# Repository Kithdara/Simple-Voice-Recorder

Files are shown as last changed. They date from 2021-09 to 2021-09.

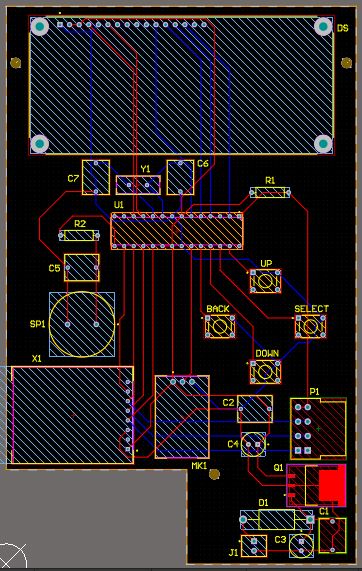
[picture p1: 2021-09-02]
Final PCB Design/Images/PCB layout - 2D view.JPG

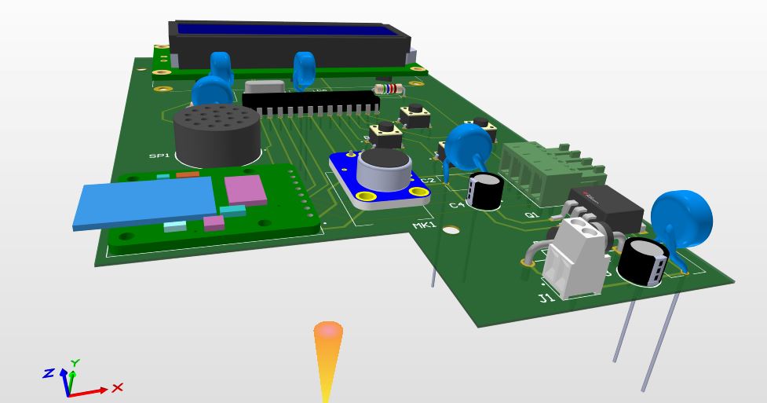
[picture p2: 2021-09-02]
Final PCB Design/Images/PCB layout - 3D view - 2.JPG

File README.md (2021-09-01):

# Simple-Voice-Recorder

We created a "Simple Voice Recorder" for our **Semester 2** Lab project at the Department of Electronic and Telecommunication Engineering, University of Moratuwa. 

**TASK** : Design and implement a simple voice recorder capable of recording, saving, selectively playing back multiple voice recordings, and adding adjustments to the spectrum during playback. 

Our project was successful in recording, saving, and playing back up to three recordings. Furthermore, we were successful in adding three adjustments; Down sampling, enhancing, shifting to the spectrum during playback. 

Recording and playback of our voice recorder are based on the **TMRpcm library** which samples at **16 kHz** and encodes **8 bits per sample**. Voice recordings were saved on an SD card. The final breadboard design, based on the **ATmega328-PU** single-chip microcontroller consists of four push buttons that interact with the user interface through an LCD. Our project is complete with a validated PCB and Enclosure design.

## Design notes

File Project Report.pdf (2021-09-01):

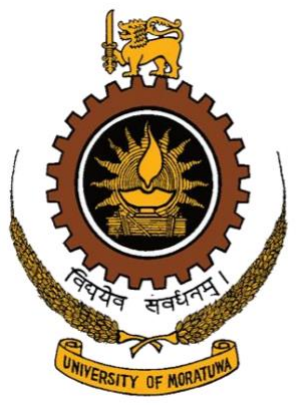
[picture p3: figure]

Priyashan, B.W.S. | 190476V
Punsara, K.K.S. | 190481G
Rajapaksha, R.M.P.A.P. | 190484T
Ranasinghe, K.K.H. | 190494A

Supervisor: Mr. Sahan Liyanaarachchi

August 2021

## Simple Voice Recorder

Department of Electronic and Telecommunication Engineering
University of Moratuwa

This report is submitted as partial fulfilment of module EN1093

## Abstract

We were given the task to design and implement a simple voice recorder capable of recording,

saving, selectively playing back multiple voice recordings, and adding adjustments to the spectrum

during playback. Our project was successful in recording, saving, and playing back up to three

recordings. Furthermore, we were successful in adding three adjustments; down sampling, enhancing,

and shifting to the spectrum during playback. Recording and playback of our voice recorder are based

on the TMRpcm library which samples at 16 kHz and encodes 8 bits per sample. Voice recordings are

saved on an SD card. The final breadboard design, based on the ATmega328-PU single-chip

microcontroller consists of four push buttons that interact with the user interface through an LCD. Our

project is complete with a validated PCB and Enclosure design.

## Table of Contents

1. Introduction.

The main goal of this project was to design and implement a simple voice recorder that

is capable to sample, encode and store the bit stream of the given sound source.

The Voice recorder that was developed by us is powered by an Atmega32

microcontroller, and it is capable of doing three main tasks. There are,

### 1. Record and save multiple voice recordings

- The Voice recorder is able to record up to 3 recordings (16 kHz

sampling rate and 8-bit PCM resolution) and save them on an SD card.

### 2. Selectively playback the recordings

- Users can select recordings that are saved in SD card through the

menu and playback them

### 3. Do minor adjustments to its spectrum during playback

- Users can add three adjustments to recordings. There are,
- Frequency shift
- Frequency scaling
- Selective enhancement of the spectrum.

In the designing stage of this project, we used many software tools such as Microchip

studio for coding, Matlab for calculations, Proteus for simulations, Altium for PCB design, and

Solidworks for enclosure design.

The following is the complete report of the challenges that we faced during the project

and how we solved them.

## 2. Methodology

### 2.1 Audio Recording / Analog to Digital Conversion

When we capture a sound wave using a microphone, it creates an analog voltage signal

proportional to the pressure variation of that sound. But, for storing, transferring, and

modifying purposes, it would be more convenient if this analog information can be converted

into a set of digital data.

The ATmega328P microcontroller includes an inbuilt ADC module that makes it

appliable in designing a voice recorder. This module has a resolution of up to 10 bits per sample

and has a conversion time from 65 to 260 µs. This module is connected to 8 multiplexed single-

ended input channels coming from the pins AD0 to AD7 of port A.

### 2.1.1 Pulse Code Modulation (PCM)

Pulse Code Modulation (PCM) is a commonly used technique to convert analog

information into digitized data. There are 3 main steps in this conversion technique.

### 1. Sampling

In this step, the analog signal is sampled at constant intervals in time known as the

Sampling Intervals. The corresponding Sampling Frequency is determined by the Nyquist

Sampling Theorem, which states that a bandlimited continuous-time signal can be sampled and

perfectly reconstructed from its samples if the waveform is sampled over twice as fast as its

highest frequency component. According to the above theorem, when implementing a Voice

Recorder, the frequency of the sampling process must be at least 8 kHz, since the highest

frequency of a voice signal is considered to be 4 kHz.

### 2. Quantizing

After the sampling process, the signal is quantized, i.e. each sample is approximated to

one of several selected discrete levels. Depending on the way of choosing these quantization

levels, this step can be achieved in two different techniques, known as Uniform and Non-

Uniform Quantization. In the Uniform Quantization, all the quantizing levels are equally

spaced in amplitude, in contrast to the Non-Uniform Quantization where the quantizing levels

are specifically chosen to capture more common lower amplitude signals in a higher resolution.

However, since the ADC module in the ATmega328P provides 1024 (= 2

10) uniform

quantizing levels, in this project, we have used a quantization method consisting of 256 (= 2

8
)

equally spaced quantizing levels. This much of a resolution is practically enough to capture

common electrical signal variations in an amplified audio signal.

### 3. Encoding

In the Encoding process, each sample is represented by a digital code unique to the

corresponding quantization level of the sample. Since a number of 2

8
levels have been used

for quantization in this case, each sample would be replaced by an 8-bit binary code; a byte.

### 2.1.2 TMRpcm Library

In this Voice Recorder Design, both the audio recording and audio playback

implementations are based on the TMRpcm library. TMRpcm is an Arduino library that

enables Asynchronous Playback of 8-bit, 8-32 kHz sampling rate, mono type WAV audio files

stored in an SD card. (The asynchronous playback specifies that the playing of an audio file

does not block the execution of the other codes in the main loop.) This library can be used on

many of the Arduino development boards such as Uno, Nano, Mega, and even on the

corresponding Atmel microcontrollers including ATmega328P.

This library provides a broad range of functions regarding audio recording and playback

and some of those main functions are listed down below.

- TMRpcm.play(filename); plays a WAV file
- TMRpcm.stopPlayback(); stops the music, but leaves the timer running
- TMRpcm.isPlaying(); returns 1 if music is playing, 0 if not
- TMRpcm.pause(); pauses/unpauses playback
- TMRpcm.volume(0); 1 (up) or 0 (down) to control volume
- TMRpcm.setVolume(0); set volume level from 0 to 7
- TMRpcm.startRecording(filename, sample rate, pin); start recording audio
- TMRpcm.stopRecording(filename); stop recording audio

Even in the TMRpcm library, the same Pulse Code Modulation (PCM) technique is

used to digitally represent the audio data. In order to understand how this PCM method is

implemented in TMRpcm, we have to take a look at how it uses the inbuilt ADC module and

the corresponding registers.

### 2.1.3 The Implementation of Analog to Digital Conversion in TMRpcm Library

Since the PRADC (Power Reduction ADC bit) of the PRR (Power Reduction Register)

has an initial value of logical 0 (i.e. power reduction is disabled), by default, the ADC module

is automatically powered up when the clock signal is supplied to the microcontroller. (refer to

Figure 1)

Figure 1 - PRR

Prior to performing any conversion, the ADC module must be enabled by setting the

ADEN (ADC Enable bit) of ADCSRA (ADC Control and Status Register - A) to a logical one.

This step is implemented in the TMRpcm library by the following line of code.

ADCSRA |= _BV(ADEN) | _BV(ADATE); //ADC Enable, Auto-trigger enable

Figure 2 - ADCSRA

Then the sampling frequency must be set for the digital conversion. The input clock

frequency for the ADC module is determined by dividing the system clock frequency (16 MHz)

by the prescaling factor given by the bit combination of the ADC Prescaler Select bits

(ADPS2:0) in the ADCSRA register. (refer to Figure 2) And when calculating the sampling

frequency, note that a normal conversion takes 13 ADC clock cycles. (refer to Table 1)

Table 1 - the sampling frequency calculation

ADPS2 | ADPS1 | ADPS0 | Prescaling Factor | ADC Clock Frequency (16 MHz / prescaling factor) | Sampling Frequency (ADC Clock frequency / 13 clock cycles)
0 | 0 | 0 | 2 | 8 MHz *
0 | 0 | 1 | 2 | 8 MHz *
0 | 1 | 0 | 4 | 4 MHz *
0 | 1 | 1 | 8 | 2 MHz *

1 | 0 | 0 | 16 | 1 MHz | 76.923 kHz
1 | 0 | 1 | 32 | 500 kHz | 38.461 kHz
1 | 1 | 0 | 64 | 250 kHz | 19.230 kHz
1 | 1 | 1 | 128 | 125 kHz #

* not achievable due to the performance limitation of the ADC module.

not achievable in the TMRpcm library

When initializing a recording using the TMRpcm library, the sampling frequency must

be given as an input to the startRecording function. Then the library will automatically set the

prescaler bits to obtain the required sampling frequency. The corresponding coding from the

library is shown below.

byte prescaleByte = 0;

if (SAMPLE_RATE < 18000) {prescaleByte = B00000110;} //ADC division factor 64 (16MHz / 64 / 13clock cycles = 19230 Hz Max Sample Rate)
else if (SAMPLE_RATE < 27000) {prescaleByte = B00000101;} //32 (38461Hz Max)
else {prescaleByte = B00000100;} //16 (76923Hz Max)

ADCSRA = prescaleByte; //Adjust sampling rate of ADC depending on sample rate
Due to the performance limitation, the maximum possible sampling frequency is

limited to 76 kHz.

By setting up the REFS1 and REFS0 (Reference Selection bits) in the ADMUX (ADC

Multiplexer Selection Register), the voltage reference for the ADC can be selected. (refer to

Figure 3 and Table 2)

Figure 3 - ADMUX

Table 2 - Reference Selection bit configuration

REFS1 | REFS0 | Voltage Reference Selection
0 | 0 | AREF, internal VREF turned off
0 | 1 | AVCC with external capacitor at AREF pin
1 | 0 | Reserved
1 | 1 | Internal 1.1V voltage reference with external capacitor at AREF pin

The TMRpcm library is set for the second voltage reference shown above, where the

voltage reference is taken through the AVCC pin by connecting it directly to the VCC and

bypassing it to the ground through a capacitor; the same configuration in an Arduino Uno

board. Rifer the following code from the TMRpcm library and Figure 3.

ADMUX |= _BV(REFS0) | _BV(ADLAR); //Analog 5v reference, left-shift result so

only high byte needs to be read

Figure 4 - Voltage Reference in an Arduino Uno

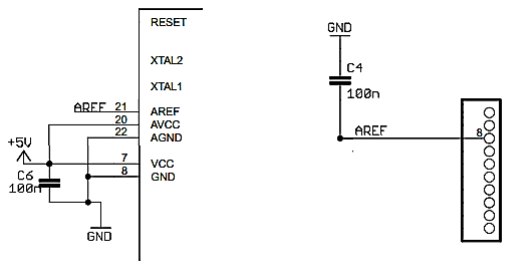
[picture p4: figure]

Then the analog input channel can be selected by changing the bits in the Analog

Channel Selection bits; MUX3:0 in the ADMUX register. Refer to Figure 3 and Table 3.

Table 3 - Analog Channel Selection bit configuration

MUX3 | MUX2 | MUX1 | MUX0 | Single-Ended Input
0 | 0 | 0 | 0 | ADC0
0 | 0 | 0 | 1 | ADC1
0 | 0 | 1 | 0 | ADC2
0 | 0 | 1 | 1 | ADC3
0 | 1 | 0 | 0 | ADC4
0 | 1 | 0 | 1 | ADC5
0 | 1 | 1 | 0 | ADC6
0 | 1 | 1 | 1 | ADC7

Same as with the sampling frequency, the pin that is used to give the analog input must

be given as an input to the startRecording function by using the corresponding Arduino analog

pin notation (from A0 to A7). This parameter (“pin”) will be then taken as a byte and the

corresponding input pin will be connected to the ADC.

#if defined(ADMUX)

ADMUX = (pin & 0x07); // same as (pin & 0b00000111)
#endif

After setting the above bit configurations, the sampling process can be begun. To start

an analog to digital conversion manually, the ADSC (ADC Start Conversion bit) in the

ADCSRA register must be written to a logical one. (refer to Figure 2) During the conversion

period, this bit will remain as a one, and when the conversion is completed, the value will return

to zero. Thus, to implement a recurring sampling process using this method, the ADSC bit has

to be written up again and again manually.

As a more convenient alternative, the Auto Triggered Mode can be used to achieve a

repeating sample-taking process. In this method, the conversion will be continuously repeated

periodically based on a trigger source selected, i.e. a conversion will be automatically started

on each positive edge of the trigger signal. To enable this auto triggered mode, a logical one

must be written to the ADC Auto Trigger Enable bit (ADATE) in ADCSRA (refer to Figure

2), and for selecting the preferred trigger source, the bit selection of the ADC Auto Trigger

Source bits (ADTS2:0) in the ADC Control and Status Register - B (ADCSRB) must be set.

Figure 5 - ADCSRB

In the TMRpcm library, a previously set timer that is created using the given sampling

rate is used as the auto trigger source. Refer to the following lines of code to see the selected

bit configuration in the ADTS bits used in the library.

ADCSRA | |= | _BV(ADEN) | | | _BV(ADATE); //ADC Enable, | Auto-trigger enable
ADCSRB | |= | _BV(ADTS0) | | | _BV(ADTS2); //Attach ADC start to TIMER1 Compare Match B

flag

After the conversion is completed, the encoded value is stored in the ADC Data

Registers which consist of two 8-bit registers; ADCL and ADCH. When the result is left-

adjusted by writing the ADLAR (ADC Left Adjust Result bit) in the ADMUX register (refer to

Figure 3), the 8 most significant bits of the 10-bit value will be written to the ADCH register

left-adjusted, and the remaining 2 bits will be written on the ADCL. (refer to Figure 6)

Figure 6 -
ADLAR and
ADCH

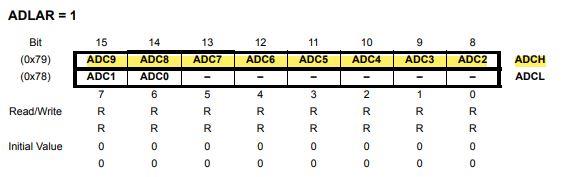
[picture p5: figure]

When only an 8-bit precision is required (as the case in the TMRpcm library), only

reading the ADCH register is enough. And then, this read encoded sample value will be

transferred into the SD card module connected to the microcontroller to be stored in the

corresponding audio recording WAV file.

This is the menu that we will see when our

voice recorder is power on.

If we select record action in the main menu,

we will go to recording menu and if we select

stop recording, we will go back to main

menu and our recording will be saved in SD

card.

If we go to recordings after record, we will

see the newly recorded file in the play list.

Also, we can go up and down and select

previously recorded recordings too.

Figure 8 - Main Menu | Figure 7 - Recording Menu

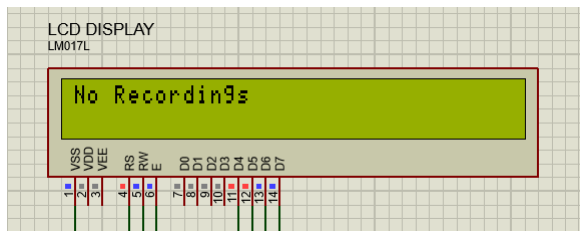
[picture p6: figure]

Figure 9 - Play List

If we go to the recordings without recording

any voice, we will be indicated that there are

no recordings.

### 2.2 User Interface

We have four push buttons to control the display. Those four buttons are up button,

down button, select button and back button.

In our user interface we have 4 main parts. Those are,

- Main menu
- Recording menu
- Play list
- Playing menu

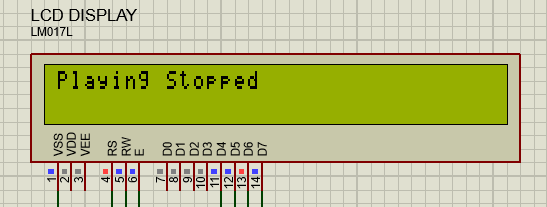
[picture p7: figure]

Figure 10 - Playing Menu

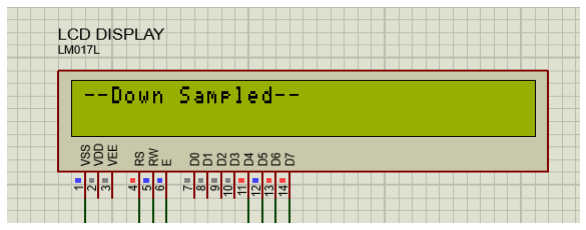
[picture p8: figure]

Figure 11

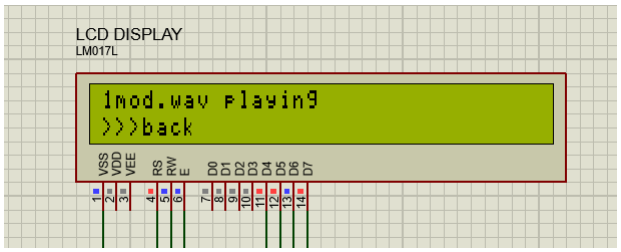
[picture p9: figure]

Figure 12

If we select a recording to play we can play it and if we select the given

back option voice recorder will stop playing the recording.

After creating the new audio file with the effect, we can play the

recording with added effect.

If we play the modified recording first voice recorder will process the audio

file and create a new modified audio file with selected effect.

### 2.3 Prototype Design

The main requirement of the project was to successfully record and save multiple

recordings. And then, selectively playback the recordings.

### 2.3.1 Breadboard design using Arduino microcontroller

Initial design of the project was done on a breadboard using the Arduino micro-

controller to implement and validate our ideas. We were successful in recording and saving up

to 3 recordings. Due to the instability of the code when program memory usage is maximum,

we had to limit the maximum number of recordings to 3.

Push buttons were successfully integrated with the LCD display for a smooth

interaction with the user interface. Voice recorded using the microphone module was sampled

at 16 kHz and encoded at 8 bits per sample using the TMRpcm library in Arduino. Recordings

were saved in .wav format. We were successful in selectively playing the 3 recordings using

the speaker. Initial design on the breadboard using the Arduino micro-controller proved

successful. Next, we shifted our prototype on the breadboard using an ATMEGA 328-PU

single-chip microcontroller.

### 2.3.2 Breadboard design using ATMEGA 328-PU

When shifting our initial design to the ATMEGA 328-PU chip microcontroller, several

codes were converted to AVR. As we implemented our main idea around the TMRpcm library,

most of the code was converted to AVR from the Arduino sketch. Since the sound source was

sampled at 16 kHz, a clock speed of 16 MHz is required. To fulfil this requirement an external

16 MHz crystal oscillator was used with the chip.

When using a 16 MHz crystal oscillator with ATMEGA 328-PU we had to first change

the “Fuse Low Bytes”. There are a total of 19 fuse bytes used in the ATMEGA 328-PU, they

can be categorized under “Extended Fuse Bye”, “Fuse High Byte” and “Fuse Low Byte”.

Setting up an external crystal oscillator does not require changing of Extended and Fuse High

Bytes.

When selecting the clock source for the ATMEGA we had to consider the following

process according to Table 4 given below. First of all, it should be noted that, a fuse byte is

unprogrammed if it is set to 1.

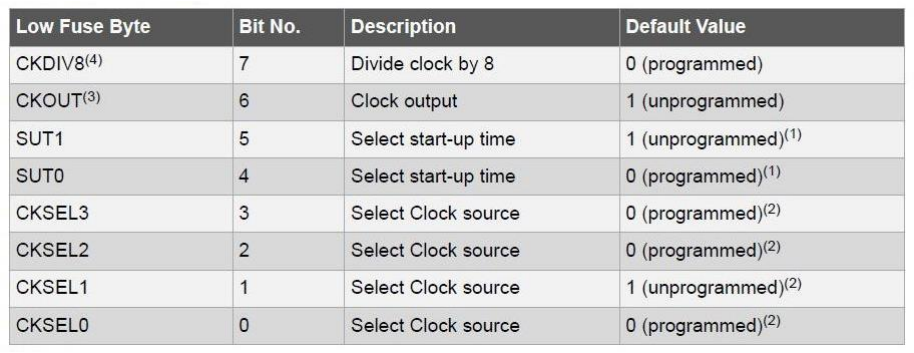
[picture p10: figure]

CKDIV8, controls whether the clock rate should be divided by 8 or not. Since, we use

an external 16 MHz crystal oscillator, bit 7 was unprogrammed (1).

CKOUT, sets whether clock output is present in PORTB0 of the microcontroller. There

was no need for this setting in our project, therefore bit 6 was unprogrammed (1).

SUT1 and SUT0 sets the startup time of the micro controller, which prevents the chip

from attempting to start before the supply voltage has had time to reach an acceptable minimum

level. Default setting of 10 is for a startup delay of six clock cycles from power-down and

power-save and an addition startup delay of 14 clock cycles plus 65ms for RESET. According

to Table 5, on the safe side for a low power crystal oscillator, a maximum delay of 16,000

clock cycles from power-down and power-save is needed. Therefore, both SUT1 and SUT0,

i.e. bits 5 and 4 is unprogrammed (1). In addition, CKSEL0, i.e. bit 0 is also unprogrammed

(1).

Table 4 - Fuse Low Byte

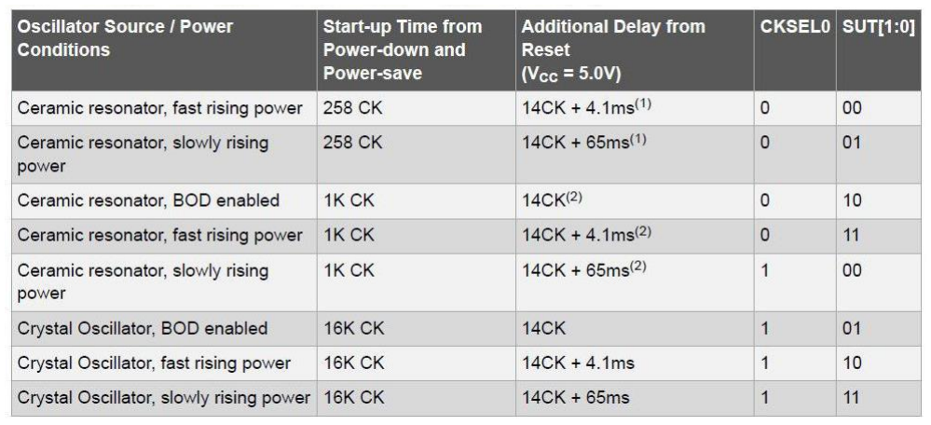
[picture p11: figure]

Bits 3 through 0 are used to select the clock source. According to Table 6, we need a

low power crystal oscillator, which means bits 3 to 0 can takes values in the range 1111 - 1000.

According to Table 7, it is stated that for a frequency range of 8 - 16 MHz CKSEL[3:1] must

be set to 111. Range of capacitors that should be connected to the oscillator is recommended

to be between 12 and 22pF. We have used two 22 pF capacitors in our design.

Table 5 - Start up times for the Low Power crystal oscillator clock selection

Table 6 - Device Clocking Options Select

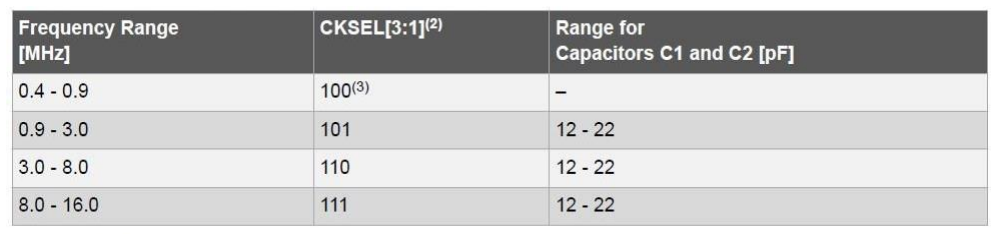
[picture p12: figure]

In conclusion,

Table 8 - Fuse Low Byte for 16 MHz crystal oscillator

CKDIV8 | CKOUT | SUT1 | SUT0 | CKSEL3 | CKSEL2 | CKSEL1 | CKSEL0
1 | 1 | 1 | 1 | 1 | 1 | 1 | 1

Therefore, the new Fuse Low Byte should be 11111111, which is 0xFF in hexadecimal

notation.

After figuring out the correct Fuse Low Byte, fuse bytes were burnt to the

microcontroller using avrdude and Arduino as ISP. AVRDUDE is command line driven utility

required to program changes to the ATMEGA 328-PU or any other Atmel microcontroller.

First, the Arduino microcontroller was connected to the laptop and “Arduino as ISP”

sketch was uploaded to the Arduino. At this stage, there should be no connections between

external components and the Arduino.

Then connections must be made between the Arduino and the microcontroller as

follows;

Arduino Pin 13 - PB5 / SCK

Arduino Pin 12 - PB4 / MISO

Arduino Pin 11 - PB3 / MOSI

Arduino Pin 10 - PC6 / RESET

After the following connections were set up, fuse low bytes were burnt to the

microcontroller. This procedure is repeated to burn hex codes to the micro controller.

We were also successful in recording, saving and playing back up to 3 recordings using

the ATMEGA 328-PU microcontroller. For the ease of shifting from Arduino prototype to the

microcontroller prototype on the breadboard, the initial connections were kept the same.

Table 7 - Low power crystal oscillator operating modes

Unfortunately, due to a fault in the microphone module, there was a significant noise

in all the recordings. Because of the noise, the clarity of the recording was quite low. But, due

to the noise the recording when played through the speaker lacked clarity. But, when the

recordings were listened from the laptop, the voice recordings could be heard even with the

noise.

PWM output from the micro-controller cannot be directly played through a speaker as

PWM is a digital signal. Therefore, a RC filter design was used as a low-pass filter and driver

for the speaker.

When calculating values for the resistor and capacitor, we wanted the cut-off frequency

to be 4kHz to allow only voice to be output to the speaker. A 0.22μF capacitor required a

resistor of 150Ω to apply the low pass filter at the required frequency. But, since a RC filter is

a passive filter design, the total output voltage had a significant decrease. This led to a low

volume output from the speaker.

Another requirement of the project was to apply adjustments to the spectrum during

playback. Although, this was not implemented in the main code due to instability, we were

successful in applying 3 effects to a recorded .wav file using the micro-controller on the

breadboard. The 3 effects namely; Down sampling, Enhance and Shifting could be

demonstrated individually in the prototype. The above effects were added to a saved recording

in the SD card, and played using the laptop. Further information on effects applied is discussed.

### 2.4 Components

### 2.4.1. Microphone module

The microphone module used for the project was GY-MAX 4466. MAX 4466 with its

in-built adjustable gain and sound amplification was ideal for our requirement. Unfortunately,

the module used in the project had a significant noise added to the recordings.

### 2.4.2. Push buttons

Four 12mm tactile push buttons were used for UP, DOWN, SELECT and BACK

functions.

### 2.4.3. LCD Display

1602A (16x2) LCD display was used in the project. A potentiometer was used to

control the brightness of the display.

### 2.4.4. SD card module

Micro-SD Memory Card adapter was used to store and playback voice recordings. The

module consists of 6 pins which include Chip Select (CS), MISO, MOSI, SCK, VCC and GND.

A 7 GB SAMSUNG SD card was used with the module.

### 2.4.5. Speaker

8 Ohm 3W speaker was used to play the stored recordings.

### 2.4.6. Capacitors

One 0.22μF capacitors was used for the RC filter design. Two 22pF capacitors were

used to connect the 16 MHz crystal oscillator to ground.

### 2.4.7. Crystal oscillator

16 MHz crystal oscillator was used with the micro-controller.

### 2.4.8. Micro-controller

ATMEGA 328PU micro controller was used for the project. This micro-controller was

used as it was readily available and ease of burning hex files using Arduino as ISP.

### 2.4.9. Resistors

One 10 kΩ resistor was used to connect RESET pin of the micro-controller to 5V. One

150Ω resistor was used in the RC filter design.

Figure 13 - (from left to right, in order) GY MAX 4466, 12 mm tactile push buttons, 1602A LCD display, Micro-SD Memory Card Adapter, 8 Ohm 3W Speaker

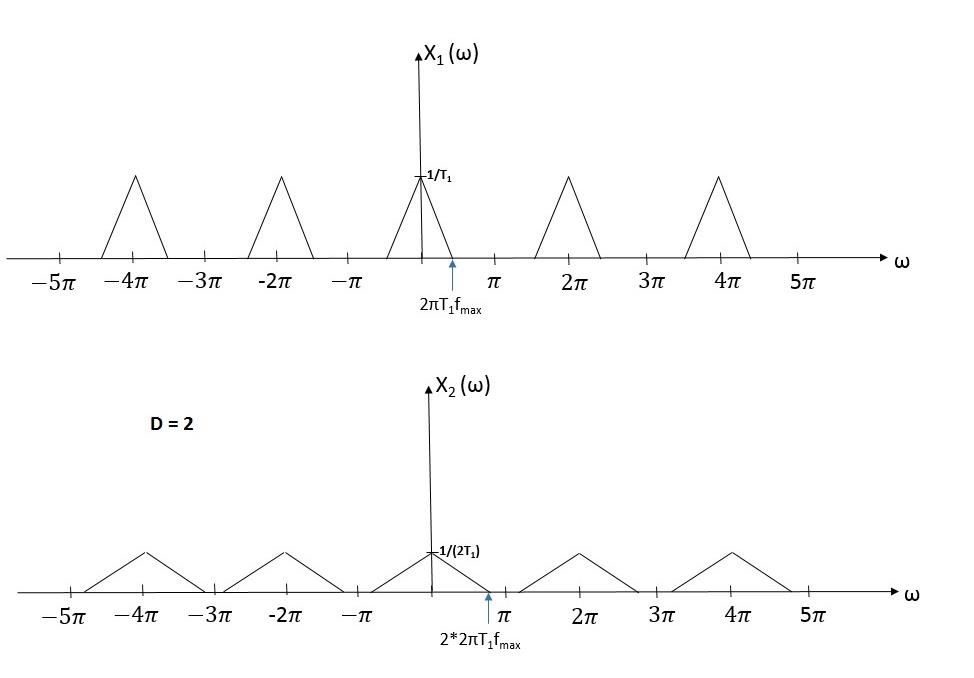
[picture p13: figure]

Figure 14 - spectrum before and after downsampling

### 2.5 Audio Enhancement Techniques

Our voice recorder has the ability to add three effects to the recorded voices. Those are

Frequency scaling, Selective Enhancing & Frequency shifting. To achieve these effects some

adjustments must be done to the spectrum of recorded voice samples. However, the processing

power of the Atmega32 microcontroller is not enough to add those changes directly to the

spectrum. So, we build algorithms to change time-domain sample values according to some

mathematical methods to achieve expected spectrum adjustments.

### 2.5.1 Frequency Scaling

The bandwidth of the recorded voice recorder is 4 kHz. The target of the frequency

scaling is, scale all frequency components in the range 0 – 8khz. To achieve this, we have to

downsample the voice file with the rate of 2. The spectrum of voice before and after

downsampling with the ratio of 2 is shown in the figure.

According to the figure, sampling frequency >= 4 × bandwidth to avoid distortion in

the spectrum.

Since the bandwidth of the voice recorder is 4 kHz, the Minimum sample rate of the

voice recorder is 16 kHz.

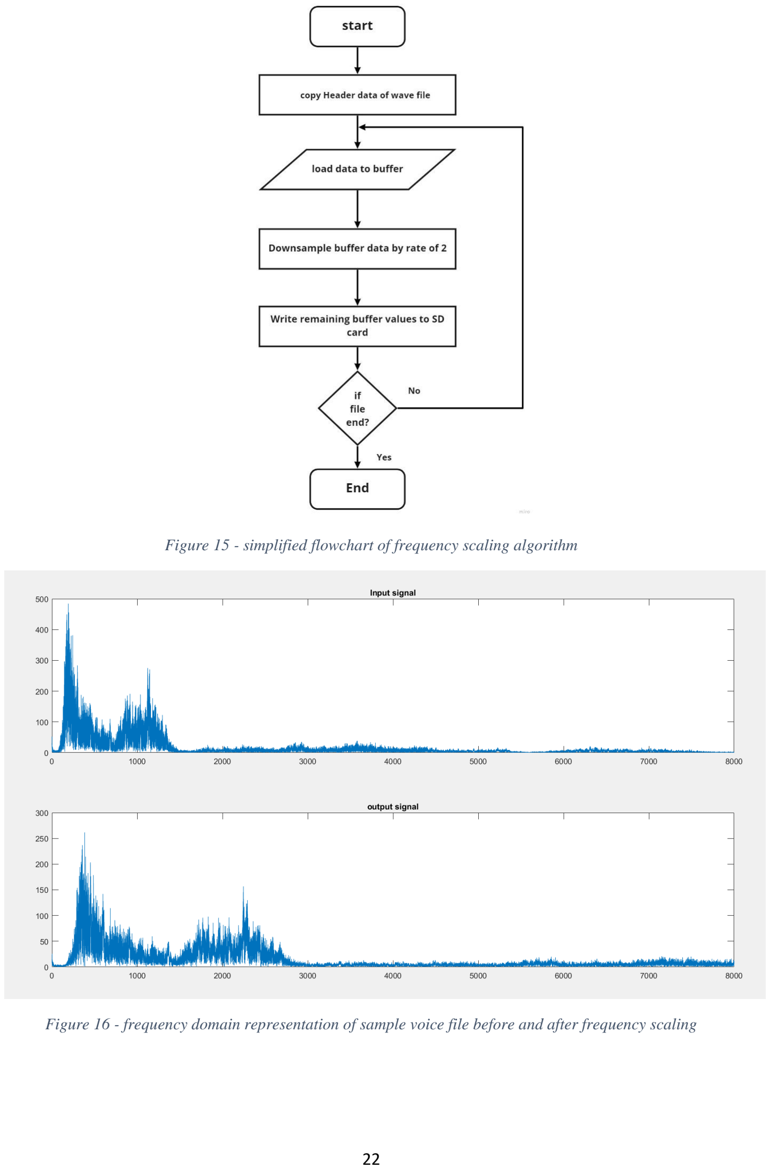
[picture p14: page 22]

Figure 15 - simplified flowchart of frequency scaling algorithm

Figure 16 - frequency domain representation of sample voice file before and after frequency scaling

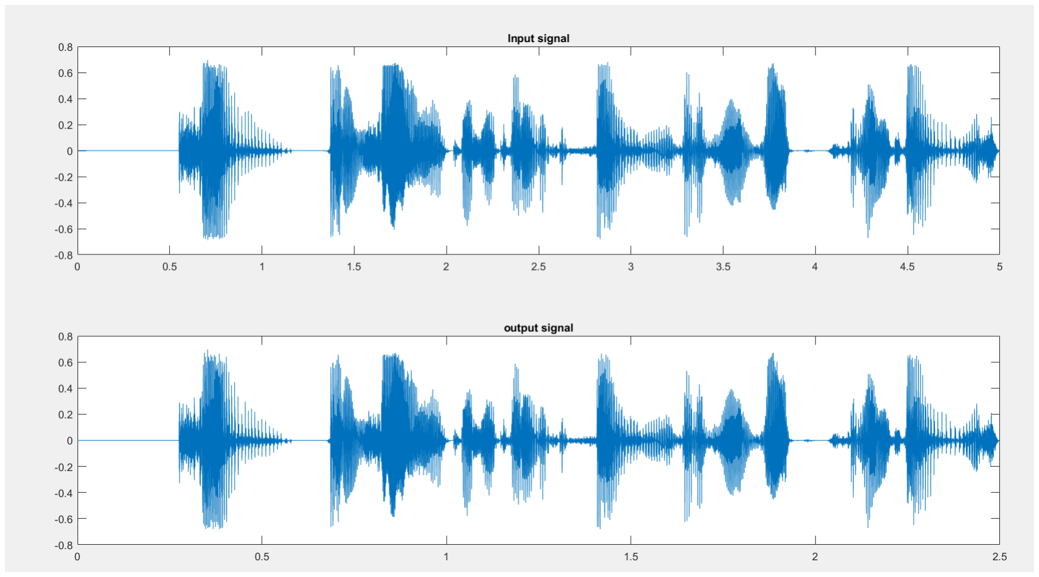
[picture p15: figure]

Figure 17 - time-domain representation of sample voice files before and after frequency scaling

### 2.5.2 Selective Enhancing

In selective enhancing, we divide the spectrum into two parts as low frequency range

(0 Hz < f < 2500 Hz) and High frequency range (2500 Hz < f < 4000 Hz). Then we enhance

the high-frequency range by increasing its amplitude by a factor of 8 and reduce the amplitude

of the low-frequency range by a factor of 1/8. However, since we are doing all calculations in

the time domain we have to use the convolution property for Fourier transform to enhance the

spectrum.

Equation 1 - convolution property

We can get filter coefficients of h(t) which have a gain of -9.03 dB for low-frequency

range and 9.03 dB gain for high-frequency range using Matlab.

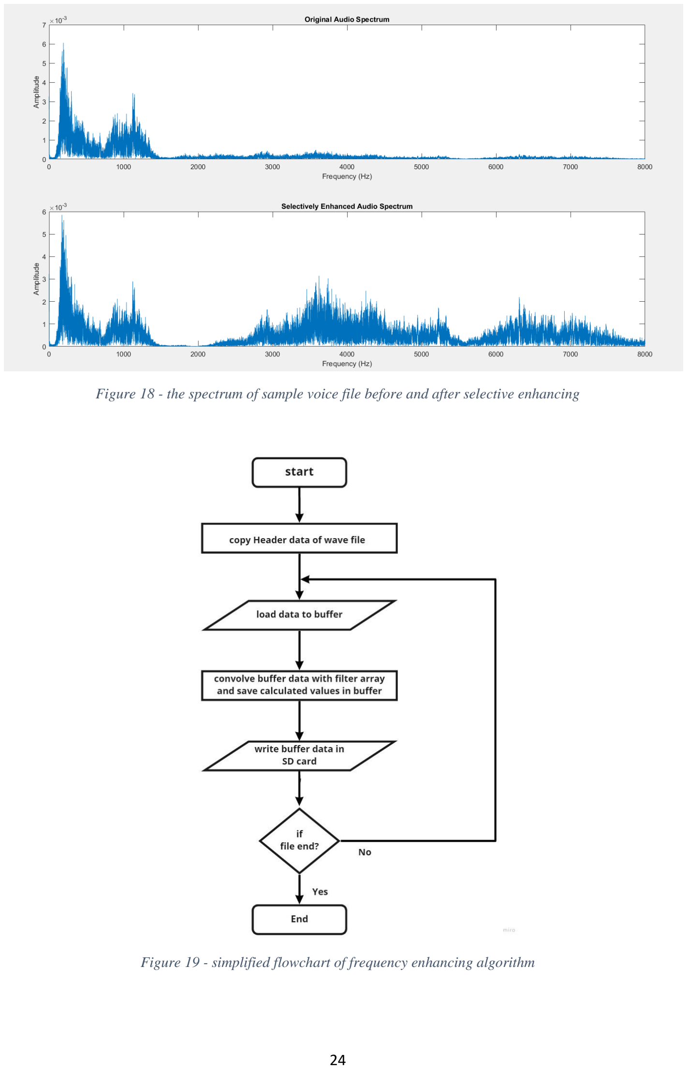
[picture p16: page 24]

Figure 18 - the spectrum of sample voice file before and after selective enhancing

Figure 19 - simplified flowchart of frequency enhancing algorithm

### 2.5.3 Frequency shifting

In the frequency shifting effect, we shift all frequency components in the spectrum to

higher frequencies by 2000 Hz. To do this process we used both convolution and multiplication

properties of Fourier transform.

Equation 2 - multiplication property

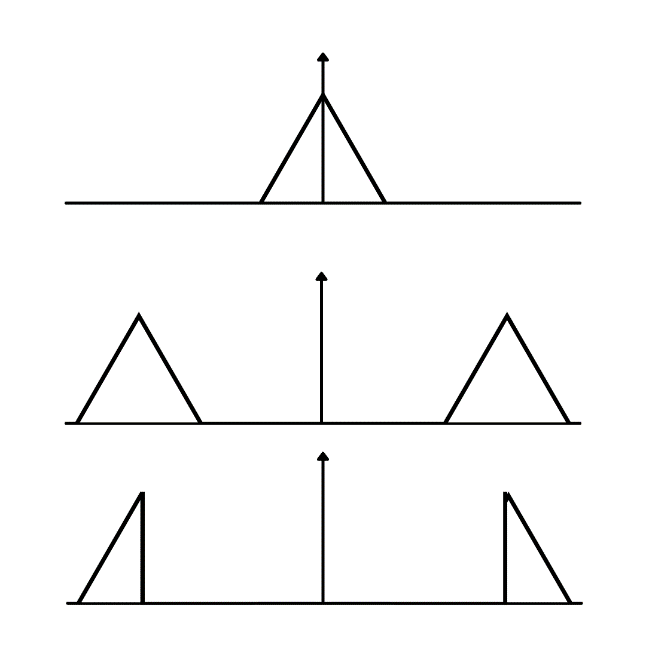
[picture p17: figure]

Figure 20 - spectrum

x(t) = voice record

y(t) = cos(2πft)

ℎ(t) = high pass filter (cutoff frequency - f)

x(t)

### x(t)y(t)

### [x(t)y(t)] *h(t)

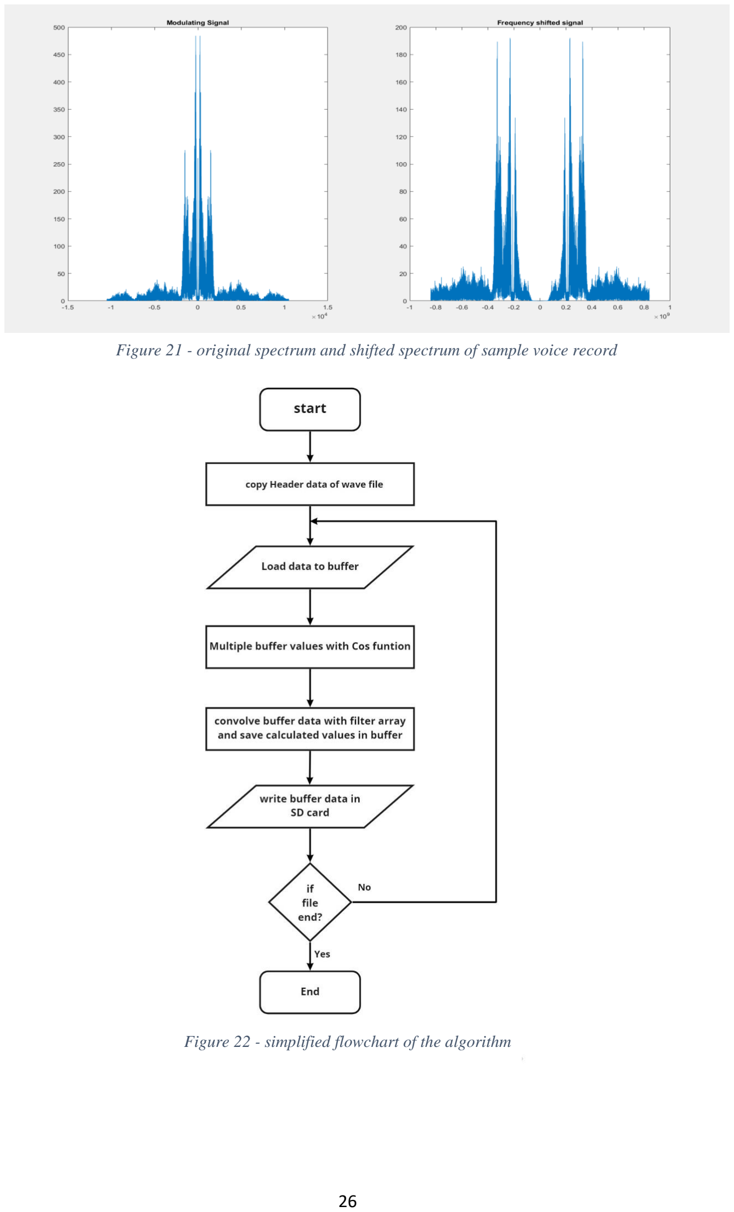
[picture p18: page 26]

Figure 22 - simplified flowchart of the algorithm

Figure 21 - original spectrum and shifted spectrum of sample voice record

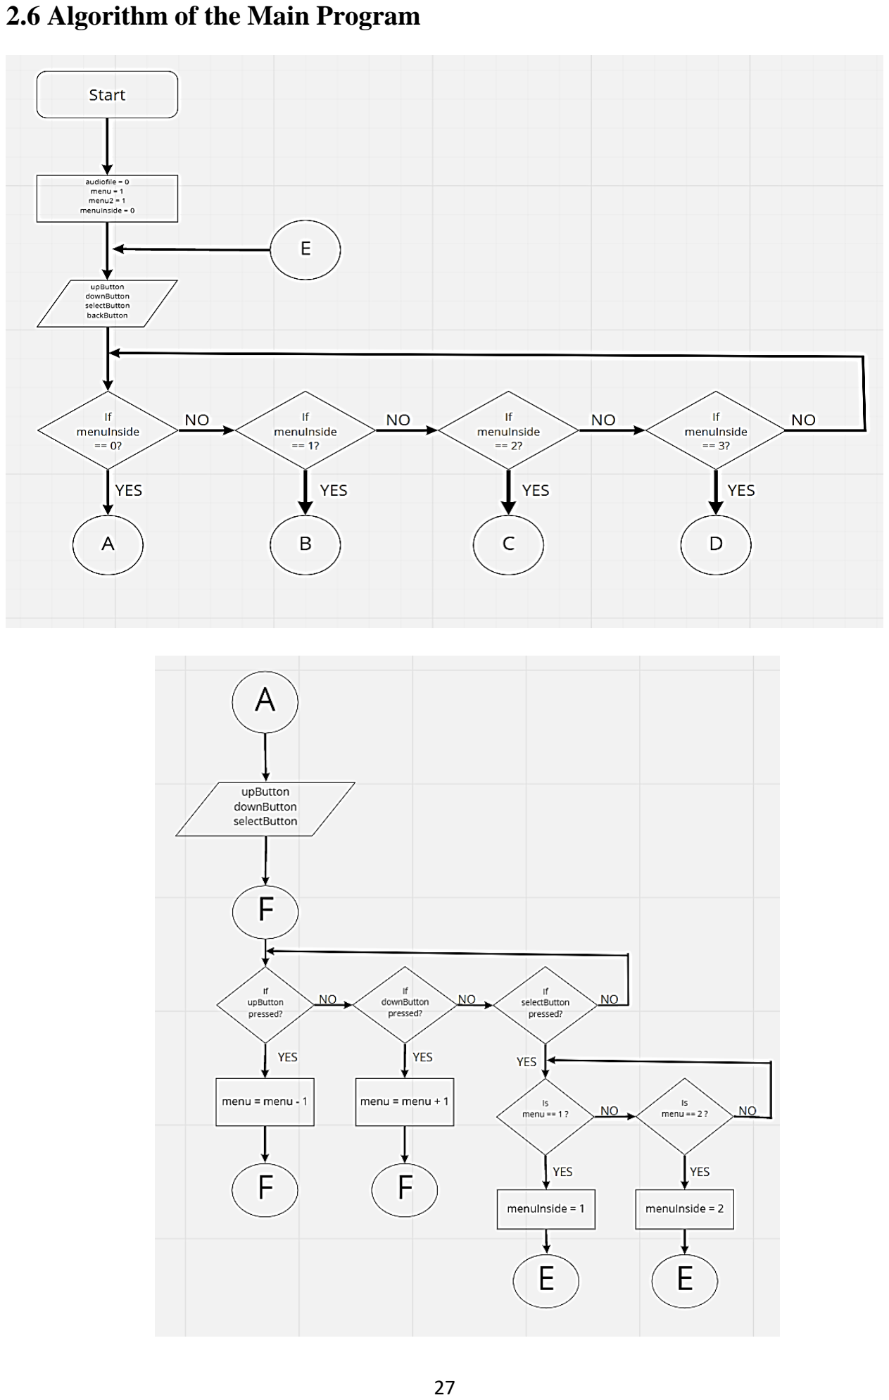
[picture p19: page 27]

### 2.6 Algorithm of the Main Program

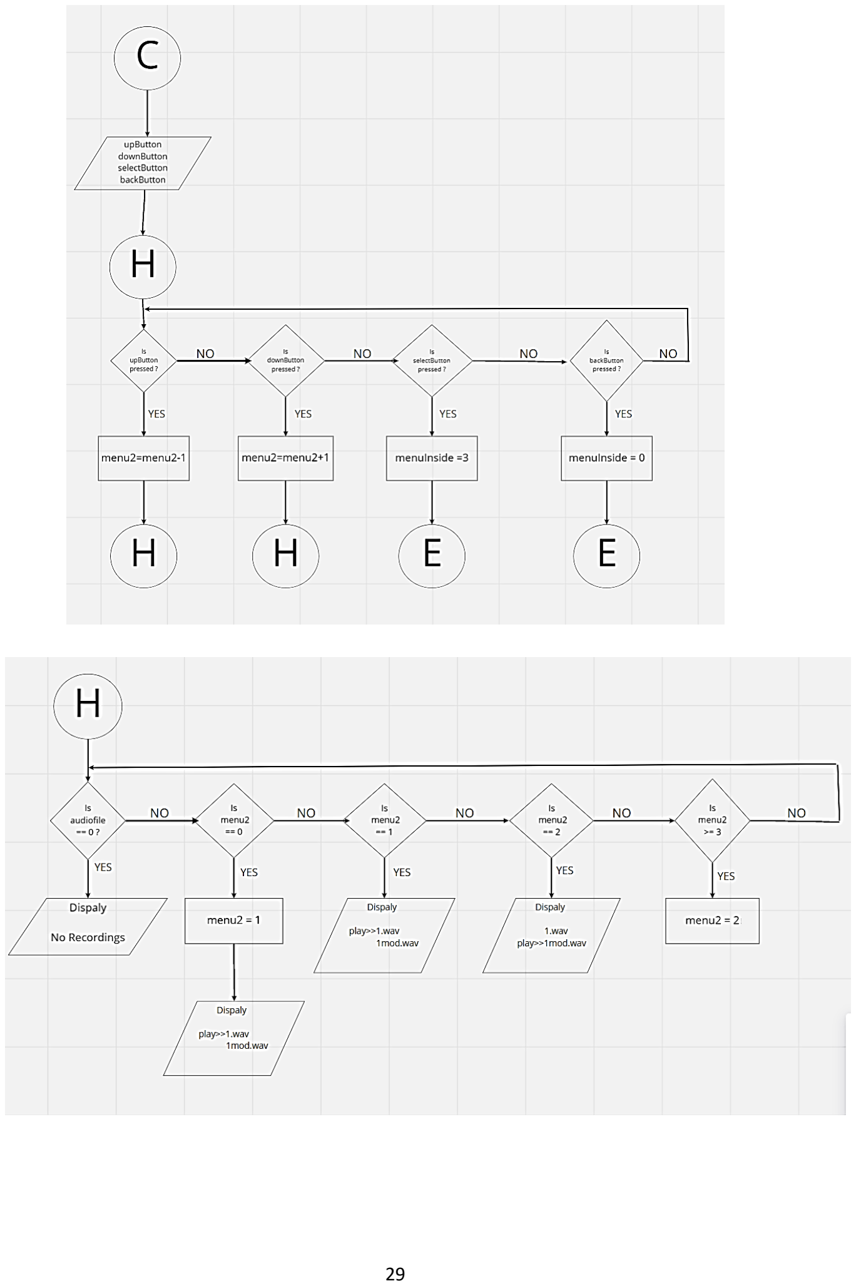
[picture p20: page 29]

## 3. Discussion

First of all, at the beginning of the project, we divided work with our four members.

Akila took the recording part and PCB designing part. Shivanka took the playback part and

breadboard implementation part. Kithdara took the Matlab coding part and adding the part of

the effects. Samal took the user interface part and enclosure designing part. The Hard-working

of our team members and correct guidance from our group instructors paves the way to a

successful project.

During this project, our team members faced some common problems. The main

problem was we had to work from home due to covid 19 pandemic situation. It was a new

experience and a challenge to us but doing regular zoom meetings with our instructors and

among us, we manage the pandemic situation. Apart from that lack of coding knowledge is

also a common problem we faced during this project. Regular group meetings and discussions

and doing research on the internet we managed to overcome that problem too.

When it comes to recording and play part, initially we tried to implement those in

Arduino simulation using RC ladder but later we used TMRpcm library. First, we tried to use

only play and record prat in library but it was unsuccessful, so we used whole library later.

Also, we managed to implement the required three effects (frequency scaling, selective

enhancing, frequency shifting) in Matlab. When we convert those 3 Matlab codes to Arduino

and AVR we faced some problems. Since the Arduino board has limited memory and ram, we

have to add additional loops and other necessary changes to implement those effects in

Arduino.

Also, we faced some problems when we combine codes to make our full code. Since

atmega328p microcontroller has limited memory and global variable memory we had to reduce

some features in the voice recorder. Finally, we were able to make a voice recorder that can

record 3 voice recordings and selectively playback the with frequency scaling effect.

When it comes to the breadboard implementation part we faced some problems too.

The main problem was due to the pandemic situation we cannot find the necessary parts needed

to project. We have to online order them and wait until they arrive. Also, we had a problem

with our microphone module and speaker module. We bought a microphone module with

adjustable gain but when we start recording from it there is a loud noise in the recorded audio file. We tried to manage that noise by adding a RC filter. We think an error in the microphone

module is the reason for this loud noise.

Also, we had a speaker module with an amplifier circuit but unfortunately, it burned.

So, we had to use an 8ohm speaker in our breadboard implementation without using

amplification. Also, in enclosure and PCB design, we faced some practical problems, but we

were able to solve them. Finally, with correct guidance and effort from our team members, our

group was able to make a working voice recorder.

## 4. References

Atmel Corporation. (n.d.). ATmega328P, 8-bit AVR Microcontroller with 32K Bytes In-System Programmable Flash, DATASHEET, ATmega328P (microchip.com) (https://ww1.microchip.com/downloads/en/DeviceDoc/Atmel-7810-Automotive-Microcontrollers-ATmega328P_Datasheet.pdf)

docr. (2019, February 27). Arduino ADC Programming. Retrieved from YouTube: https://youtu.be/YYE9jq5sXo4

Hienzsch, D. (n.d.). Arduino from scratch part 10 - ATmega328P subsystem. Retrieved from Rheingold Heavy: https://rheingoldheavy.com/arduino-from-scratch-part-10-atmega328p-subsystem/ (https://rheingoldheavy.com/arduino-from-scratch-part-10-atmega328p-subsystem/)

Smyth, T. (2019, October 15). Nyquist Sampling Theorem. Retrieved from http://musicweb.ucsd.edu/~trsmyth/digitalAudio171/Nyquist_Sampling_Theorem.html

TMRpcm/Home, https://github.com/TMRh20/TMRpcm/wiki, 2020

Learn About ATmega328P Fuse Bits and How to Use Them with an External Crystal Oscillator, Learn About ATmega328P Fuse Bits and How to Use Them with an External Crystal Oscillator -Projects (allaboutcircuits.com)

LCD interfacing with ATMEGA32 AVR MICROCONTROLLER, https://microcontrollerslab.com/lcd-interfacing-atmega32-avr-microcontroller/ (https://microcontrollerslab.com/lcd-interfacing-atmega32-avr-microcontroller/)

## 5. Appendices

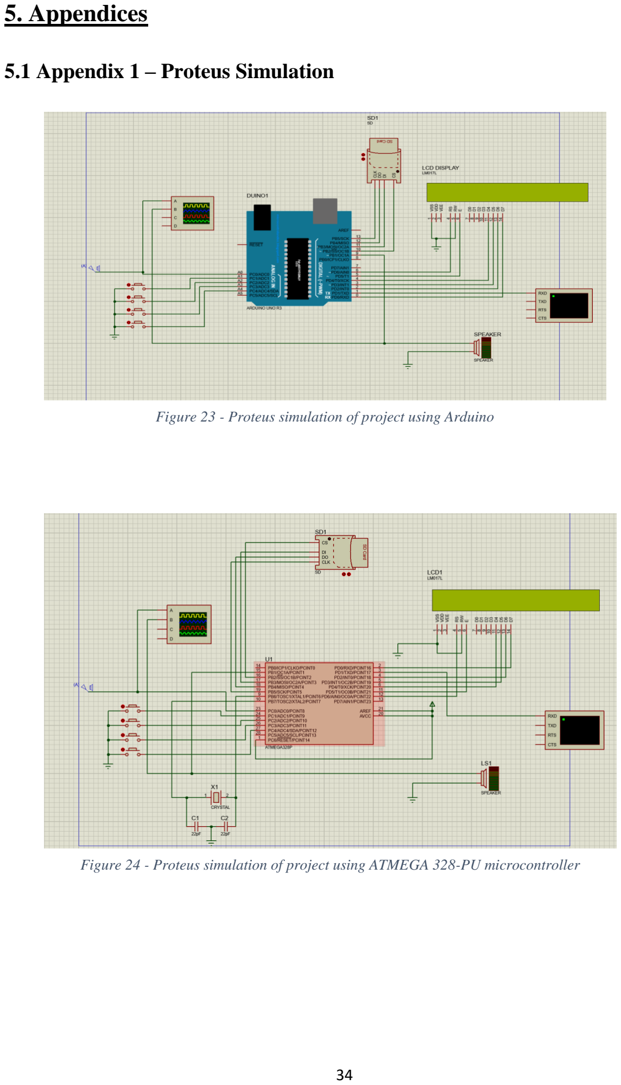
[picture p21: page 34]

### 5.1 Appendix 1 – Proteus Simulation

Figure 23 - Proteus simulation of project using Arduino

Figure 24 - Proteus simulation of project using ATMEGA 328-PU microcontroller

### 5.2 Appendix 2 – Breadboard Implementation

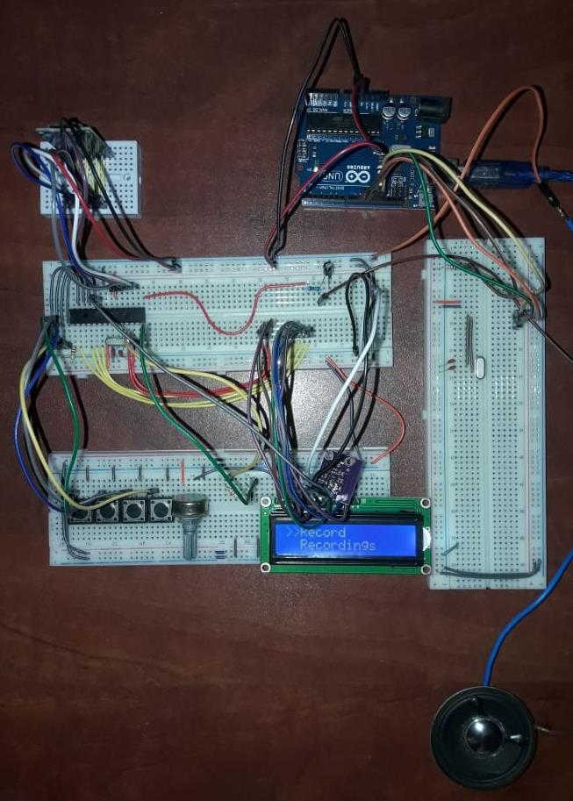
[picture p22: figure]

Figure 25 - Prototype on breadboard using ATMEGA 328-PU microcontroller

## 5.3 Appendix 3 - PCB Schematic

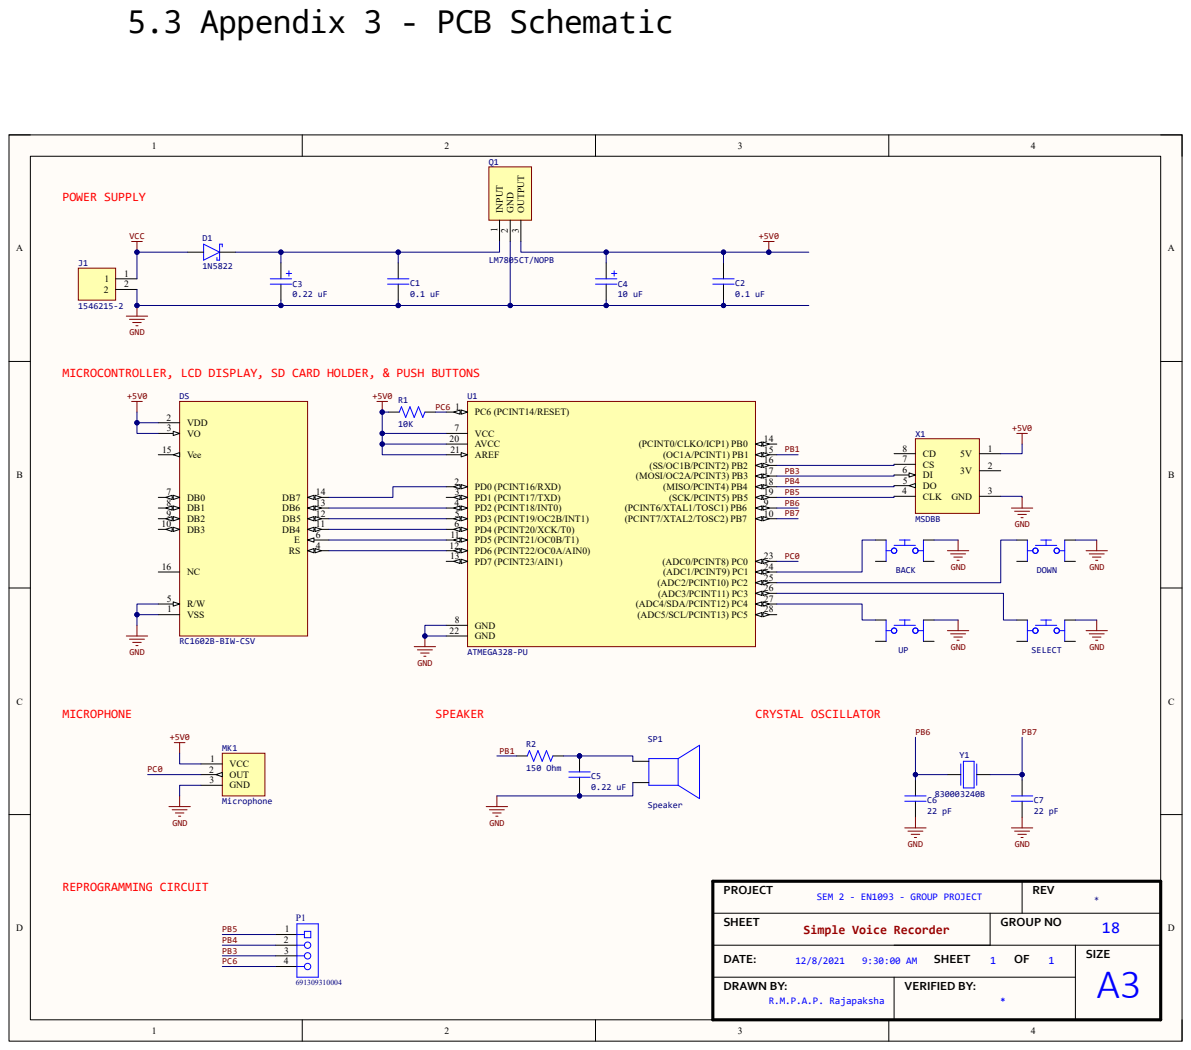
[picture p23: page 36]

MICROCONTROLLER, LCD DISPLAY, SD CARD HOLDER, & PUSH BUTTONS

PROJECT SEM 2 - EN1093 - GROUP PROJECT | REV *

SHEET Simple Voice Recorder | GROUP NO 18

DATE: 12/8/2021 9:30:00 AM SHEET OF 1 1 | SIZE

DRAWN BY: | VERIFIED BY:

## 5.4 Appendix 4 - PCB Layout

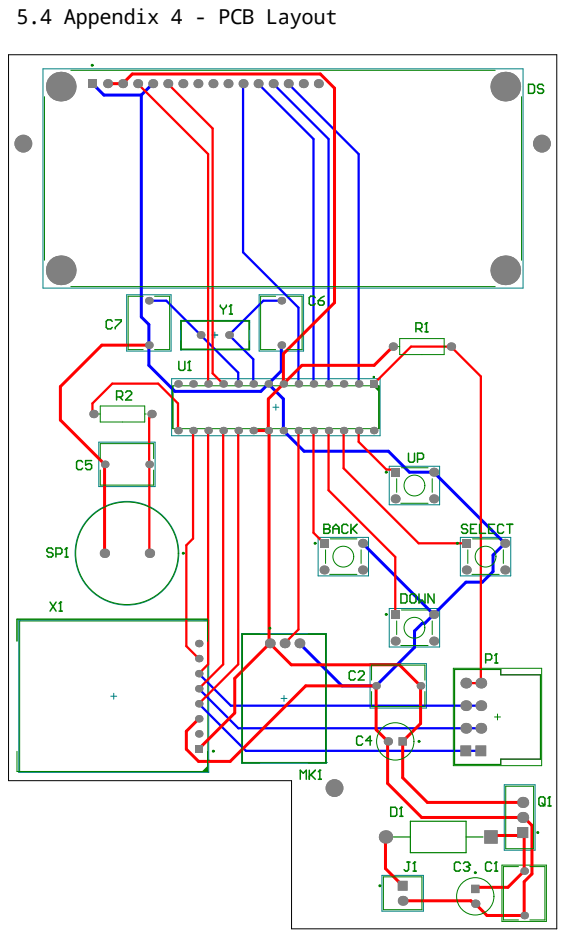
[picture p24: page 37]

Appendix II - PCB Layout

### 5.5 Appendix 5 – PCB 3D View

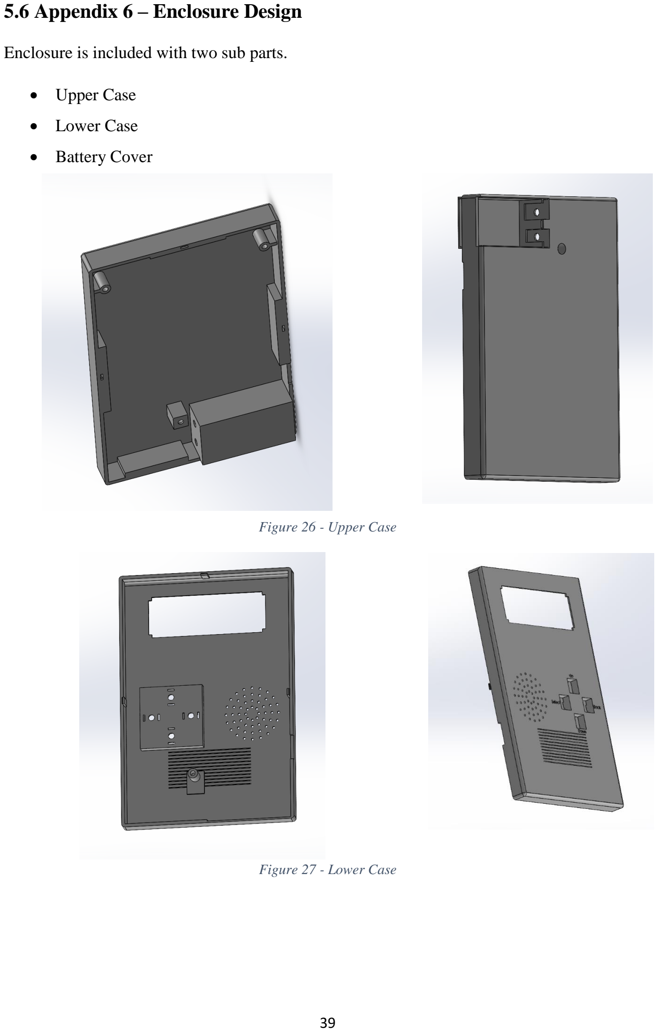
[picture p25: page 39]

Figure 26 - Upper Case

Figure 27 - Lower Case

### 5.6 Appendix 6 – Enclosure Design

Enclosure is included with two sub parts.

- Upper Case
- Lower Case
- Battery Cover

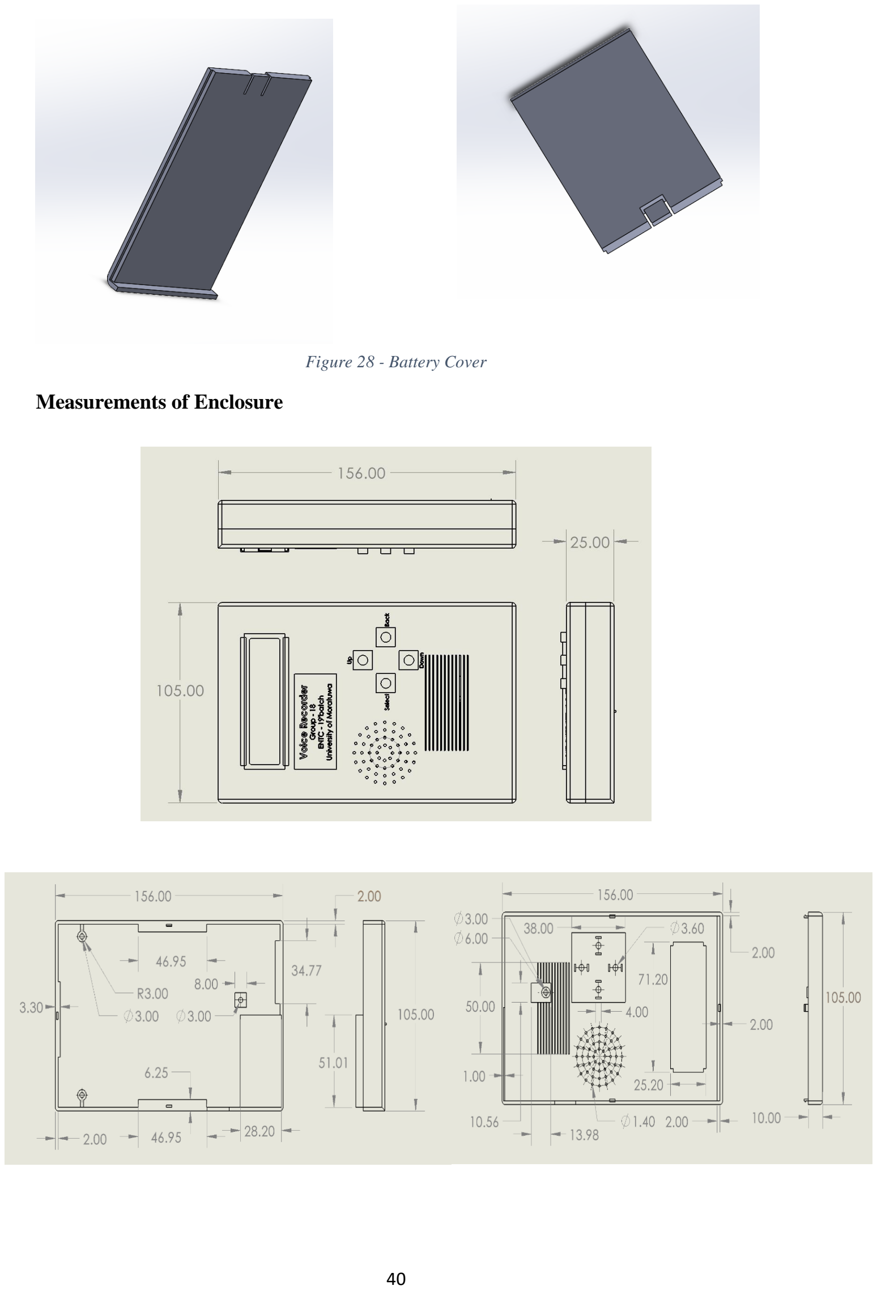
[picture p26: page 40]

Figure 28 - Battery Cover

Measurements of Enclosure

Color

- Case – Grey
- Push Buttons – Black
- Name Plate – Blue

Mass Properties

- Material used - Acrylonitrile Butadiene Styrene (ABS) Plastic
Part Name | Mass (g) | Total (g)
Upper Case | 29.03 | 29.03
Lower Case | 53.91 | 53.91
Push Buttons | 0.59×4 | 2.36
Battery Cover | 2.78 | 2.78
Battery | 37 | 37
PCB | 140 | 140
Total | | 265.08

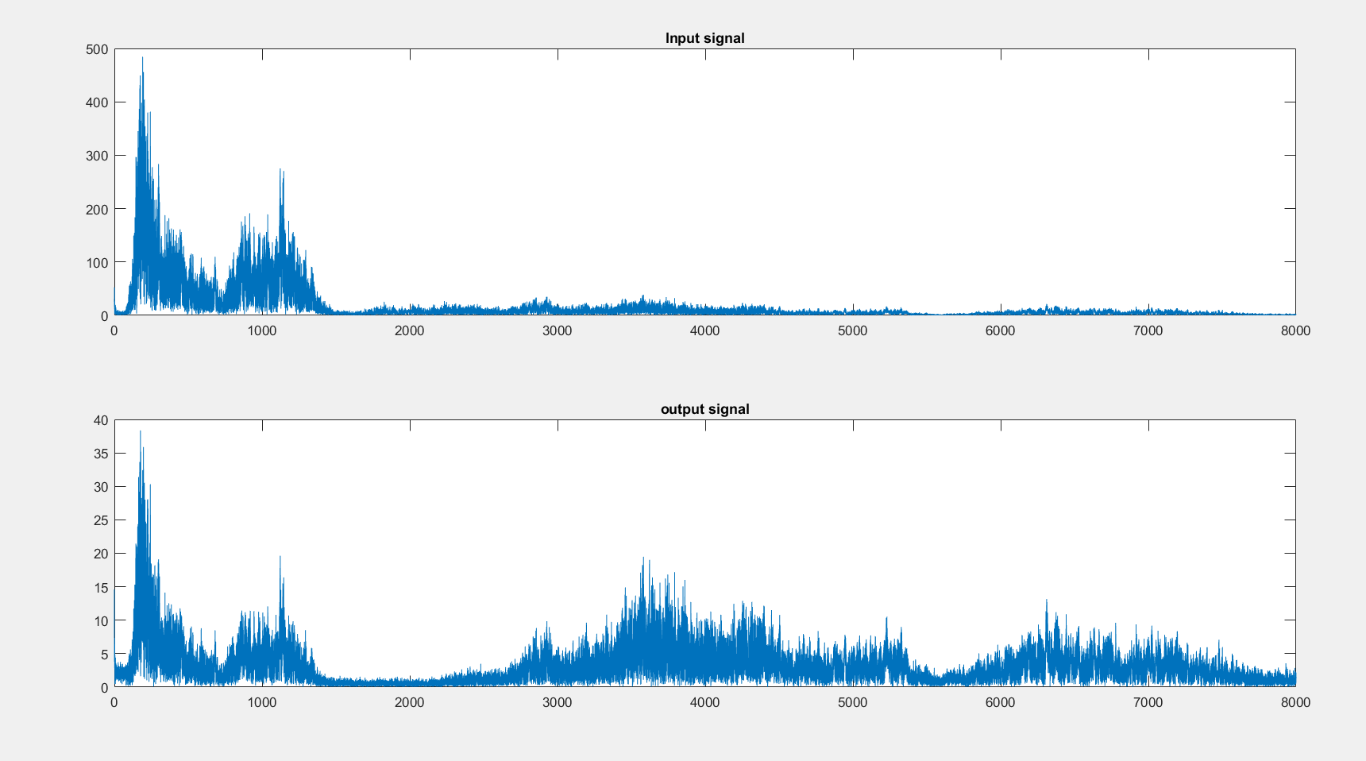
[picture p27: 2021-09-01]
simulations of spectrum changes/selective_enhance/Photos/Selective enhancing Spectrum (Arduino).png

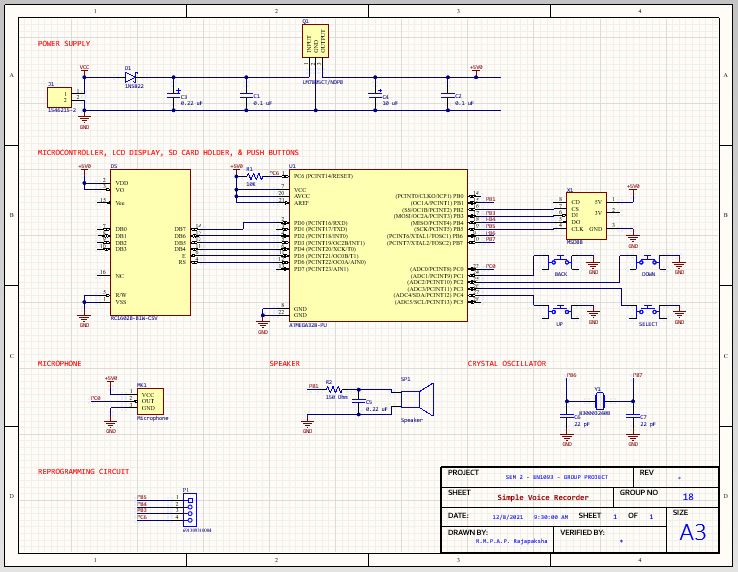
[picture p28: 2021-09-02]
Final PCB Design/Images/PCB schematic.JPG

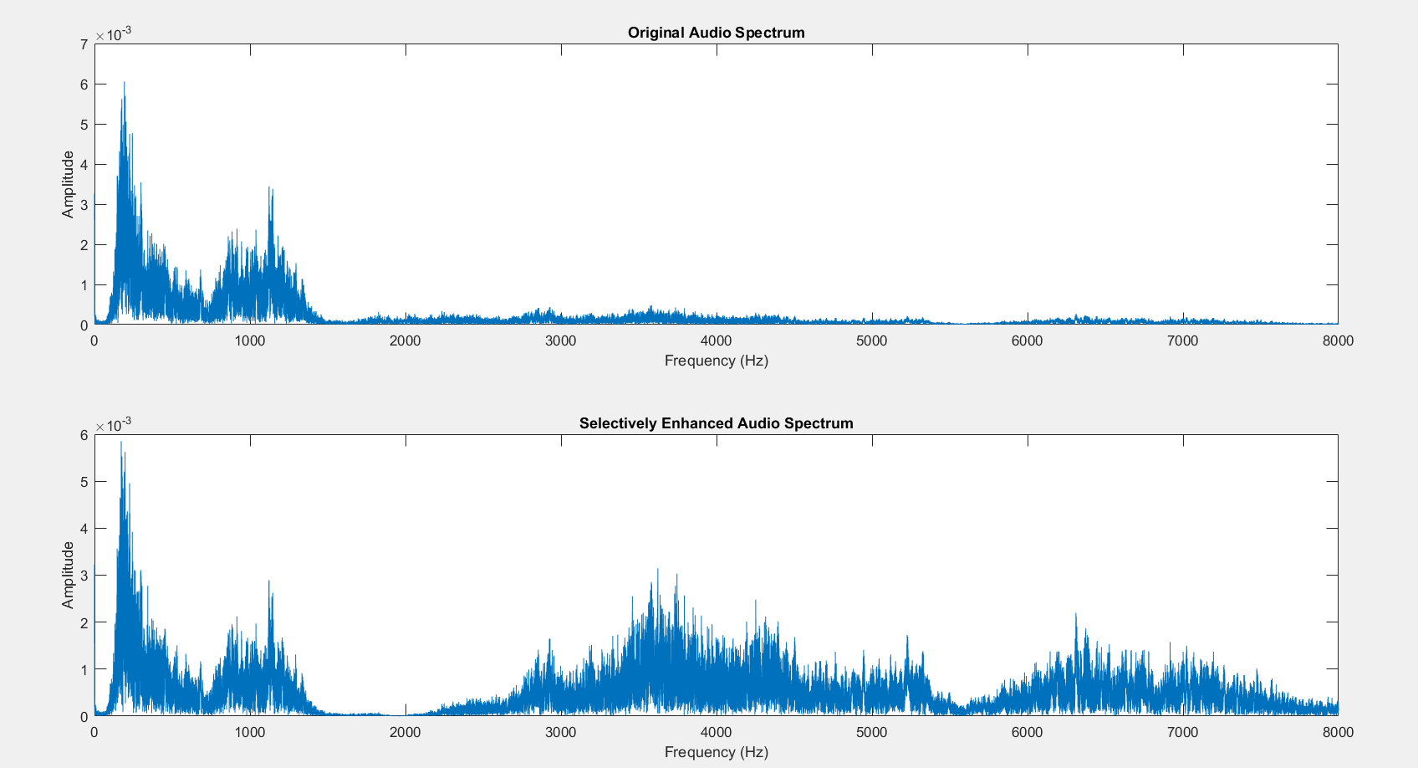
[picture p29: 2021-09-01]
simulations of spectrum changes/selective_enhance/Photos/Selective enhancing Spectrum (Matlab).png

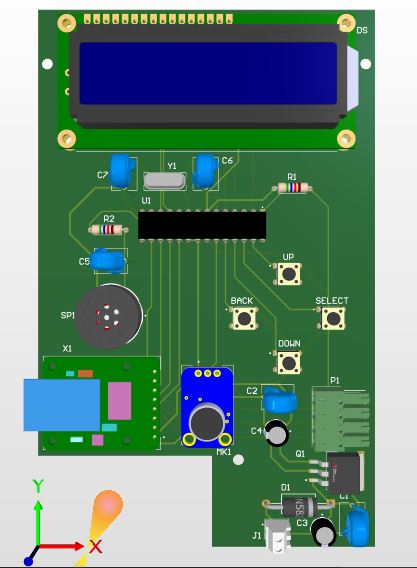
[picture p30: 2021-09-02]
Final PCB Design/Images/PCB layout - 3D view - 1.JPG

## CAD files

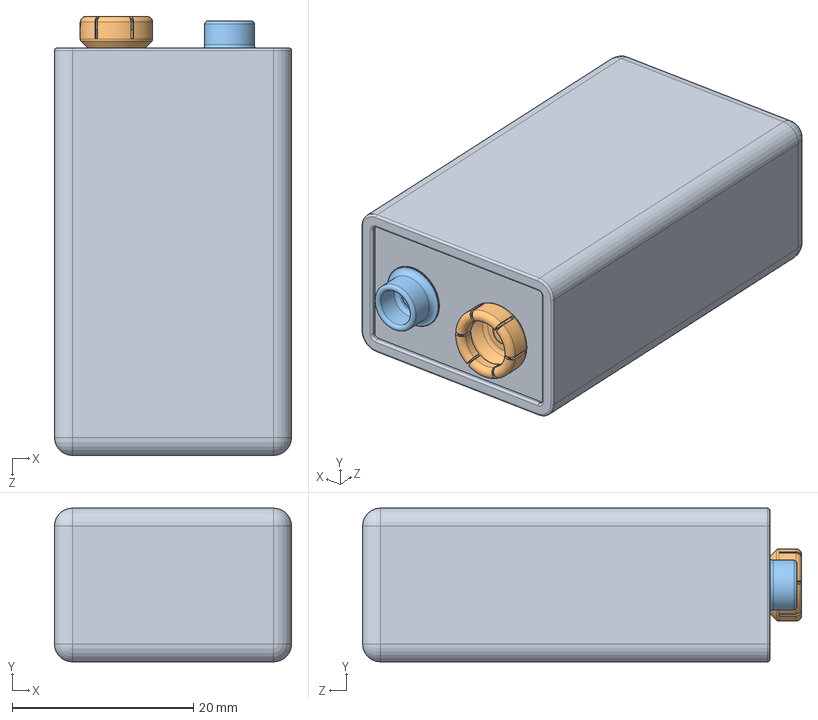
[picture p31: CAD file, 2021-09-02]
Final Enclousre Design/battery-9v-pile-9v-1.snapshot.1/Batterie 9V.SLDASM
26.2 x 17.0 x 48.5 mm
Corps Batterie
Connecteur femelle Batterie 9V
Connecteur male Batterie 9V

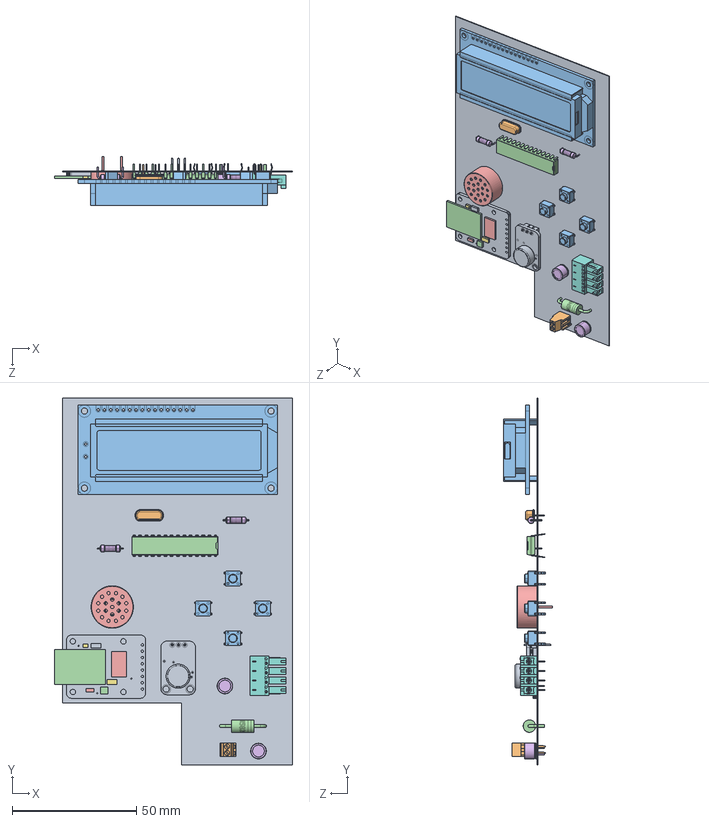
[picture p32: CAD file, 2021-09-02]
Final Enclousre Design/pcb 3d model/Sem 2 Lab Project - Simple Voice Recorder - 3D Model.step.SLDASM
95.8 x 147.5 x 19.8 mm
User_Library-HP49US.step
Ada_microsd.step x 2
Ada_microsd-0.step
Ada_microsd-1.step x 2
Ada_microsd-2.step
Ada_microsd-3.step x 2
Ada_microsd-4.step
Ada_microsd-5.step x 2
Ada_microsd-6.step
Ada_microsd-7.step x 2
Ada_microsd-8.step
Ada_microsd-9.step x 2
Ada_microsd-10.step
Ada_microsd-11.step x 2
Ada_microsd-12.step
Ada_microsd-13.step x 2
Ada_microsd-14.step
1825910-6--3DModel-STEP-1.step x 4
atmega328-pu.step
6278910512.step
RESAD1000W56L850D270-000-300_SEI_CF12.step x 2
6913093100xx_Pin.step x 4
691307300004.step
Max4466.step
1546215-2--3DModel-STEP-1.step
RC1602B-BIW-CSV--3DModel-STEP-56544_(1).step
User_Library-Schottky_Barier_Rectifier_Diodes_1N5822_(pcb).step x 2
User_Library-Schottky_Barier_Rectifier_Diodes_1N5822_(pcb)-15.step
CAPPRD250W50D630H500-V-000-300.step x 2

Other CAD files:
Final Enclousre Design/pcb 3d model/R2.step.SLDASM
Final Enclousre Design/pcb 3d model/DOWN.step.SLDASM
Final Enclousre Design/pcb 3d model/MK1.step.SLDASM
Final Enclousre Design/pcb 3d model/U1.step.SLDASM
Final Enclousre Design/pcb 3d model/J1.step.SLDASM
Final Enclousre Design/pcb 3d model/Board.step.SLDASM
Final Enclousre Design/pcb 3d model/C4.step.SLDASM
Final Enclousre Design/pcb 3d model/X1.step.SLDASM
Final Enclousre Design/pcb 3d model/BACK.step.SLDASM
Final Enclousre Design/pcb 3d model/SP1.step.SLDASM
Final Enclousre Design/pcb 3d model/R1.step.SLDASM
Final Enclousre Design/pcb 3d model/SELECT.step.SLDASM
Final Enclousre Design/pcb 3d model/P1.step.SLDASM
Final Enclousre Design/pcb 3d model/D1.step.SLDASM
Final Enclousre Design/pcb 3d model/UP.step.SLDASM
Final Enclousre Design/pcb 3d model/Y1.step.SLDASM
Final Enclousre Design/Name plate.SLDPRT
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

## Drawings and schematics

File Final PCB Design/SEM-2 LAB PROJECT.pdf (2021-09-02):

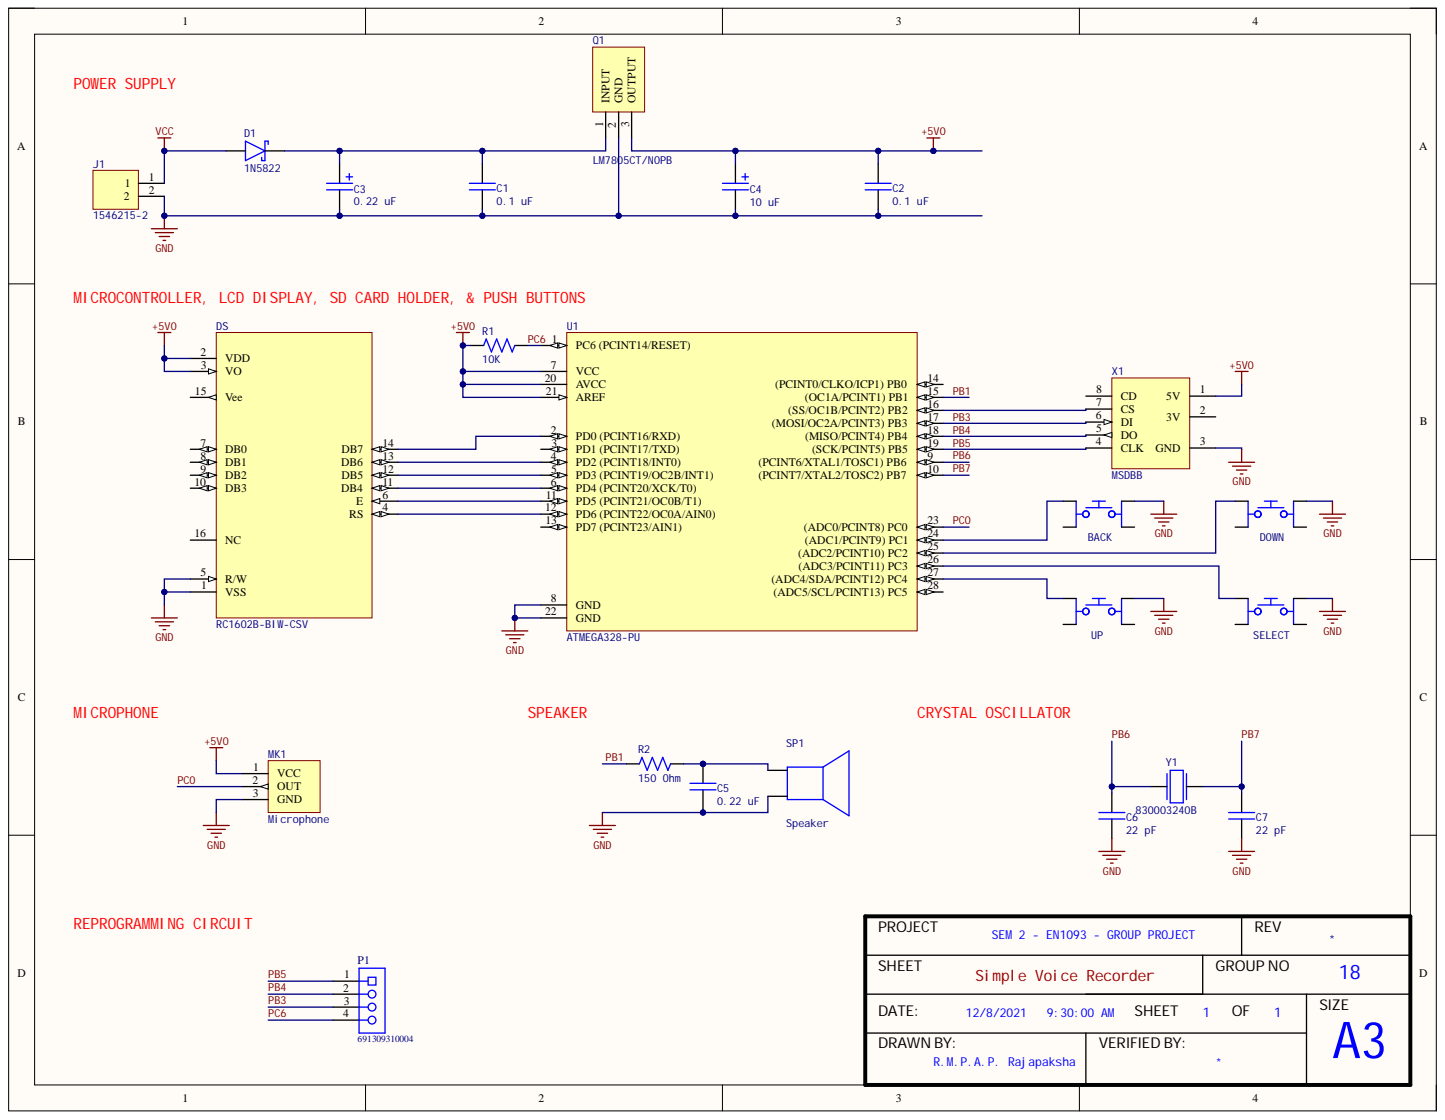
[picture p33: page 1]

MICROCONTROLLER, LCD DISPLAY, SD CARD HOLDER, & PUSH BUTTONS

PROJECT SEM 2 - EN1093 - GROUP PROJECT | REV *

SHEET Simple Voice Recorder | GROUP NO 18

DATE: 12/8/2021 9:30:00 AM SHEET 1 OF 1 | SIZE A3
R.M.P.A.P. Rajapaksha DRAWN BY: | * VERIFIED BY:

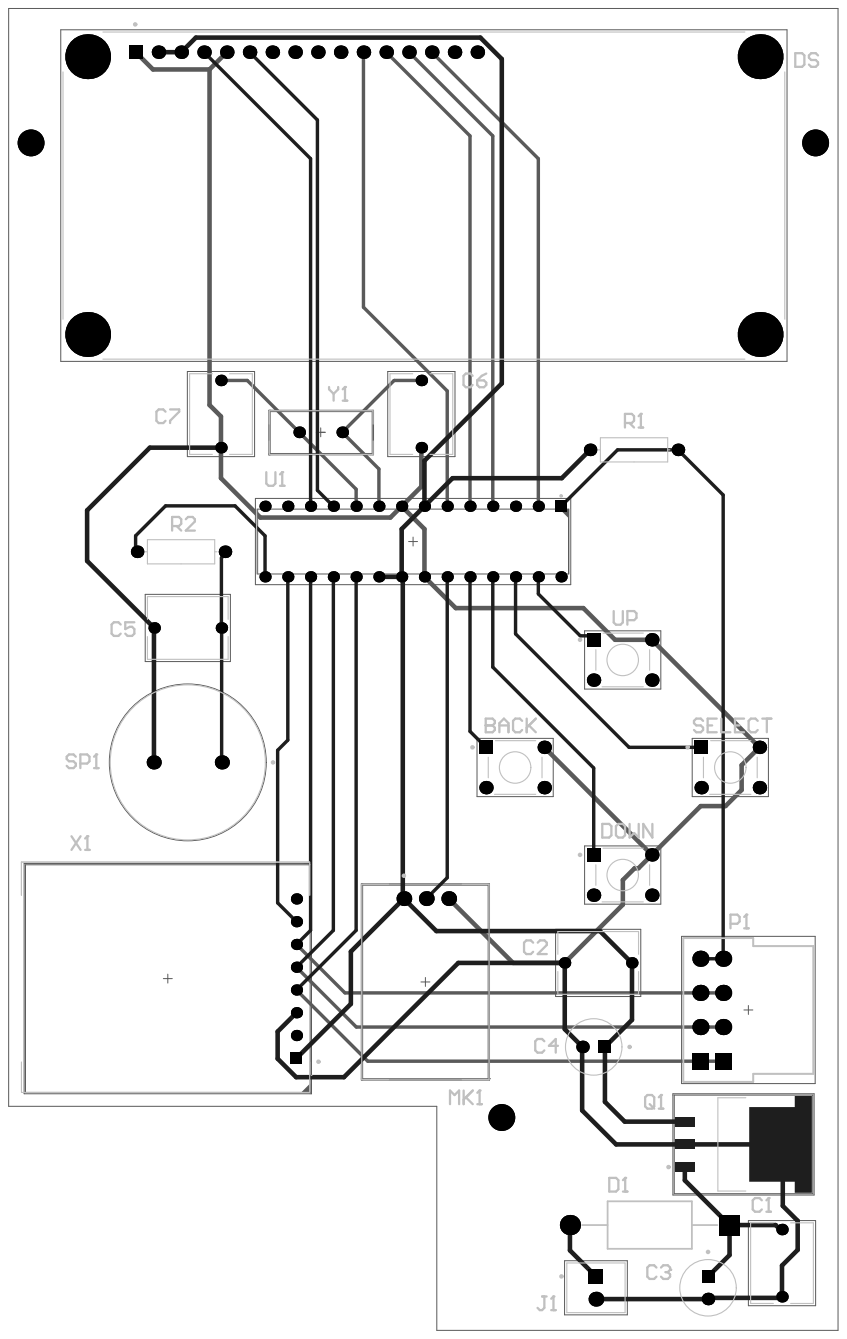
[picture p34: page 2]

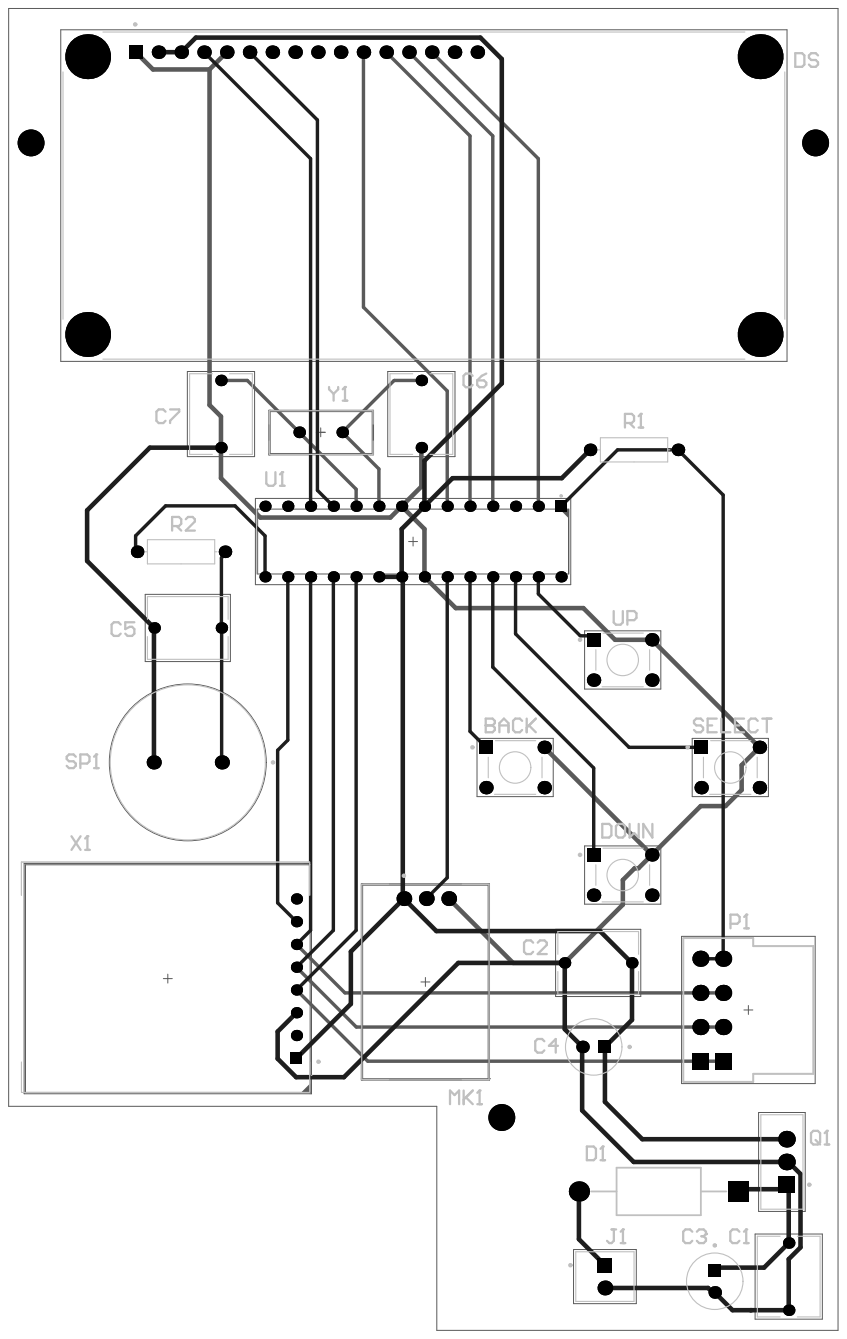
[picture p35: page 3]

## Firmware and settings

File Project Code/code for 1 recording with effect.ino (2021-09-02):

#include <SD.h>
#include <SPI.h>
#include <TMRpcm.h>
#define SD_ChipSelectPin 10
#include <LiquidCrystal.h>
LiquidCrystal lcd(6, 5, 4, 3, 2, 0);
TMRpcm audio,player;
unsigned long i=0;
int upButton=A1;
int downButton=A2;
int selectButton=A3;
int backButton=A4;
int audiofile=0;
int menu=1;
int menu2=1;
int menuInside=0;
void setup() {
  lcd.begin(16, 2);
  pinMode(upButton, INPUT_PULLUP);
  pinMode(downButton, INPUT_PULLUP);
  pinMode(selectButton, INPUT_PULLUP);
  pinMode(backButton, INPUT_PULLUP);

  updateMenu();
  pinMode(A0, INPUT);
  SD.begin(SD_ChipSelectPin);
  audio.CSPin = SD_ChipSelectPin;
  audio.speakerPin = 9;

}

void loop() {
  if (!digitalRead(downButton) and menuInside==0){ // decrease 'menu' to go down in main menu
    menu++;
    updateMenu();
    delay(500);
    while (!digitalRead(downButton));
  }
  if (!digitalRead(downButton) and menuInside==2 and audiofile and menu2<4){ // decrease 'menu2' to go down in saved recordings
    menu2++;
    recordHistory();
    delay(500);
    while (!digitalRead(downButton));
  }
  if (!digitalRead(upButton) and menuInside==0){ // increase 'menu' to go up in main menu
    menu--;
    updateMenu();
    delay(500);
    while (!digitalRead(upButton));
  }
  if (!digitalRead(upButton) and menuInside==2 and audiofile and menu2>1){ // increase 'menu2' to go up in saved recordings
    menu2--;
    recordHistory();
    delay(500);
    while (!digitalRead(upButton));
  }
  if (!digitalRead(selectButton) and menuInside==0 and menu==1){ // go to record action from main menu and start recording
    button();
    menuInside=1;
    updateMenu1();
    delay(500);
    while (!digitalRead(selectButton));
  }
  if (!digitalRead(selectButton) and menuInside==1){ //go to recording display from 'record' in main menu and stop recording
    button();
    menuInside=0;
    updateMenu();
    delay(500);
    while (!digitalRead(selectButton));
  }
  if (!digitalRead(selectButton) and menuInside==0 and menu==2){ //go to saved recordings from 'recordings' in main menu
    menuInside=2;
    recordHistory();
    delay(500);
    while (!digitalRead(selectButton));
  }
  if (!digitalRead(backButton) and menuInside==2){ // go back from saved recordings to 'recordings' in main meny
    if (audiofile){
      menu2=audiofile; 
    }
    menuInside=0;
    updateMenu();
    delay(500);
    while (!digitalRead(backButton));
  }
  if (!digitalRead(selectButton) and menuInside==2 and audiofile){ //select a saved audio file from saved recordings and play it
    menuInside=3;
    playmenu();
    delay(500);
    while (!digitalRead(selectButton));
  }
  if (!digitalRead(selectButton) and menuInside==3){ // stop playing the recording and go back to saved recording list
    menuInside=2;
    lcd.clear();
    lcd.print("Playing Stopped");
    delay(1000);
    //audio.pause();// stop playing
    recordHistory();
    delay(500);
    while (!digitalRead(selectButton));
  }
}
void updateMenu() {
  if (menu == 0) {
      menu = 1;
  }
   if (menu == 1) {
      lcd.clear();
      lcd.print(">>Record");
      lcd.setCursor(0, 1);
      lcd.print("  Recordings");
  }
   if (menu == 2) {
      lcd.clear();
      lcd.print("  Record");
      lcd.setCursor(0, 1);
      lcd.print(">>Recordings");
  }
   if (menu == 3) {
      menu=2;
   }
}
void updateMenu1() {
  if (menu2<=4){
    lcd.clear();
    lcd.print("----Recording---");
    lcd.setCursor(0, 1);
    lcd.print(">>Stop Recording");
  }
  else{
    menu2=4;
    lcd.clear();
    lcd.print("Capacity exceed");
    lcd.setCursor(0, 1);
    lcd.print(">>Back");
  }
}
void button() {
  while (i < 300000) {
    i++;
  }
  i = 0;
  if (menuInside==0) {
    audiofile++;
    menu2=2*audiofile-1;
    switch (audiofile) {
      case 1: audio.startRecording("1.wav", 16000, A0); break;
    }
  }
  else {
    switch (audiofile) {
      case 1: audio.stopRecording("1.wav"); break;
    }
  }
}


void recordHistory(){
  if (audiofile==0){
    lcd.clear();
    lcd.print("No Recordings");
  }
  if (menu2==1 and menu2<=2*audiofile) {
    lcd.clear();
    lcd.print("play>>---1.wav--");
    lcd.setCursor(0, 1);
    lcd.print("    >>-1mod.wav-");
  }
  if (menu2==2 and menu2<=2*audiofile ){
    lcd.clear();
    lcd.print("    >>---1.wav--");
    lcd.setCursor(0, 1);
    lcd.print("play>>-1mod.wav-");
  }
//  if (menu2==3 and menu2<=2*audiofile) {
//    lcd.clear();
//    lcd.print("play>>---2.wav--");
//    lcd.setCursor(0, 1);
//    lcd.print("    >>-2mod.wav-");
//  }
//  if (menu2==4 and menu2<=2*audiofile ){
//    lcd.clear();
//    lcd.print("   >>---2.wav--");
//    lcd.setCursor(0, 1);
//    lcd.print("play>>-2mod.wav-");
//  }
  if (menu2>3){
    menu2=2;
  }
  if (menu2>2*audiofile){
    menu2=2*audiofile-1;
  }
}


void playmenu(){
  if (menu2 == 1 and menu2<=2*audiofile) {
    lcd.clear();
    lcd.print("1.wav playing");
    lcd.setCursor(0, 1);
    lcd.print(">>>back");
    //player.setVolume(6);
    //player.play("1.wav");
  }
  if (menu2 == 2 and menu2<=2*audiofile ){
    downsample("1.wav","1mod.wav");
    lcd.clear();
    lcd.print("1mod.wav playing");
    lcd.setCursor(0, 1);
    lcd.print(">>>back");
    //player.setVolume(6);
    //player.play("1mod.wav");
  }
//  if (menu2 == 3 and menu2<=2*audiofile) {
//    lcd.clear();
//    lcd.print("2.wav playing");
//    lcd.setCursor(0, 1);
//    lcd.print(">>>back");
//    //player.setVolume(6);
//    //player.play("2.wav");
//  }
//  if (menu2 == 4 and menu2<=2*audiofile ){
//    downsample("2.wav","2mod.wav");
//    lcd.clear();
//    lcd.print("2mod.wav playing");
//    lcd.setCursor(0, 1);
//    lcd.print(">>>back");
//    //player.setVolume(6);
//    //player.play("2mod.wav");
//  }
}
void downsample(char* filename,char* out_name){
File myFile;
File outputFile;
unsigned long  i=0;
unsigned long  fileSize;
char *buff; 
SD.remove(out_name);
myFile = SD.open(filename);
fileSize=myFile.size();
outputFile = SD.open(out_name, FILE_WRITE);
buff=(char*)malloc(128); 
while (i!=80) {
  outputFile.write(myFile.read());
  i+=1;
}   
myFile.read(buff,128);
lcd.clear();
lcd.print("--Down Sampling-");
delay(500);
while (myFile.available()) {
  i+=128;
  for (int j=0;j<64;j++){
    buff[j]=buff[2*j];       
  }
  outputFile.write(buff,64);
  if(fileSize-i<128){
    break;
    }
   myFile.read(buff,128);
}
myFile.close();
outputFile.close();
lcd.clear();
lcd.print("--Down Sampled--");
delay(500);  
}

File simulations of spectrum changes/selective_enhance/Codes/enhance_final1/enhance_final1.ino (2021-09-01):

#include <SPI.h>
#include <SD.h>
//This fillter enhance the High frequency(>2.5kHZ) range by increasing its amplitude by a factor of 8, and reducing the amplitude of Low Frequency (<2.5KHZ)range by a factor of 1/8.
 double h[]={0  , -0.0029 ,  -0.0049  ,  0.0054 ,   0.0262 ,   0.0177 ,  -0.0594   ,-0.1730 ,   0.3816 ,  -0.1706  , -0.0508  ,  0.0343  ,  0.0465 ,   0.0220 ,   0.0037 ,-0.0005  ,  0.0005};
File myFile;
File outputFile;
const int h_length = 17;  //length of filter
double Data[h_length];   // array to save sample values that need to convolution
int   counter=0;         // counter varible
int temp;             // The values read from the wav file are temporarily sretained by this variable
double sum=0;            //result of convolution by this variable Y[n] = x[n]*h[n]
char buffer1[256];



void setup() {
  
  // Open serial communications and wait for port to open:
  Serial.begin(9600);
  while (!Serial) {
    ; // wait for serial port to connect. Needed for native USB port only
  }
   Serial.print("Initializing SD card...");

  if (!SD.begin(4)) {
    //Serial.println("initialization failed!");
    while (1);
  }
  //Serial.println("initialization done.");

 //remove  existing files   
 SD.remove("male_out.wav");  
  
 // open the file for reading and Writing
 myFile = SD.open("male.wav");
 outputFile = SD.open("male_out.wav",FILE_WRITE);

 
Serial.println("processing.........");

 // copy header data of wave file to new wav file
while (counter!=78) {
    outputFile.write(myFile.read());
    counter++;
    }



//---------------convoltion--------------------


//load samaple values to Data array
for (int j=0;j<h_length;j++){
  Data[h_length-j-1]=myFile.read();
  }


// start convoltion

// Number of overlapping is less than length of array "h" and overlaping is increasing in this part.
for (int i=0;i<h_length;i++){
  sum=0;
  for (int j=0;j<i+1;j++){
    sum+=h[j]*Data[h_length-1-i+j];
  }
  temp=sum+125;
  outputFile.write(temp);
  }
  



//Number of overlapping is similar to length of "h".
counter=0;
  while(myFile.available()){
    for(int k =h_length -1;k>0;k--){
      Data[k]=Data[k-1];
    }
    Data[0]=myFile.read();
    sum=0;
    for(int i =0;i<h_length;i++){
      sum += Data[i]*h[i];
    }
    temp=sum+125;
      buffer1[counter]=temp;
      counter++;
      if (counter >=255){
        outputFile.write(buffer1,255);
        counter=0;
      }  
    }

    
// number of overlapping is decreasing.
  for (int i=0;i<h_length -1;i++){
    sum=0;
    for(int j;j<h_length - i-1;j++){
      sum += Data[h_length-i-j-2]*h[h_length-1-j];
    }
    temp=sum+125;
    outputFile.write(temp);
  }
 
Serial.println("_________Done_____________");


//close files
myFile.close();
outputFile.close();
}



void loop() {
  

}

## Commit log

2021-09-01 Add final project Report
    Project report contains information of all the theories used in our design. Includes images of
    breadboard implementation, enclosure designs, PCB designs, algorithms.
2021-09-02 Add files via upload
    Contains the following files;
    - Finalized Schematic document
    - Finalized PCB document
    - Images of schematic and PCB layout
    [Sem 2 Lab Project - Simple Voice Recorder - Finalized Doc.PcbDoc, Sem 2 Lab Project - Simple Voice Recorder.SchDoc]
2021-09-02 Add image of final prototype
    Final prototype on breadboard using ATmega328-PU microcontroller
